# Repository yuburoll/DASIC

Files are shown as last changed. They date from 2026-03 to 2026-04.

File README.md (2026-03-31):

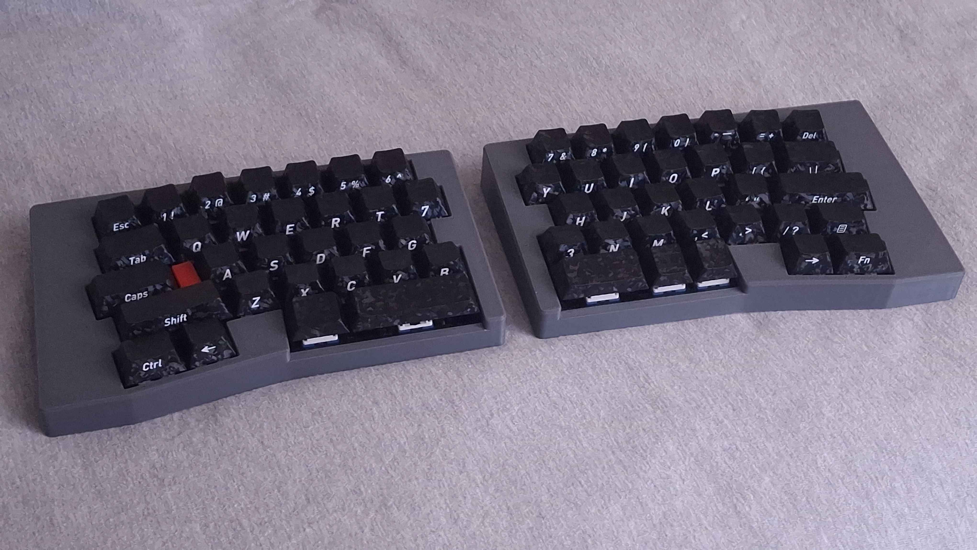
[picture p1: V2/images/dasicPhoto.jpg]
dasicPhoto


# DASIC

(pronounced like DAH-sick)

60-64 key symmetrical row stagger alice style wired split keyboard

The name "dasic"(dasik) is korean traditional dessert, and also is korean pun of [ansic](https://github.com/yuburoll/ANSIC) with many key.

[**V2 README**](V2/README.md)

[**V2 3.75u README**](V2-375u/README.md)

[**V1 README**](V1/README.md) (deprecated since May 22, 2026)

# 다식

60-64 좌우대칭 앨리스 배열 스플릿 키보드

키 수 많은 [안식](https://github.com/yuburoll/ANSIC)이라는 농담을 치고 싶었습니다.

[**V2 설명서**](V2/README_ko.md)

[**V2 3.75u 설명서**](V2-375u/README_ko.md)

[**V1 설명서**](V1/README_ko.md) (2026년 3월 22일부터 지원 종료)

## Licenses

all codes follow MIT license.

all designs and the hardware board follow CC BY-SA 4.0 license.

If you want to make a commercial product, it would be appreciated if you sponsor some bucks for me.

## 라이센스

모든 코드는 MIT license를 따릅니다.

모든 디자인과 하드웨어 보드는 CC BY-SA 4.0 license를 따릅니다.

본 디자인을 가지고 상업활동을 하고 싶으시다면, 몇 푼 정도 후원해주시면 감사하겠습니다...

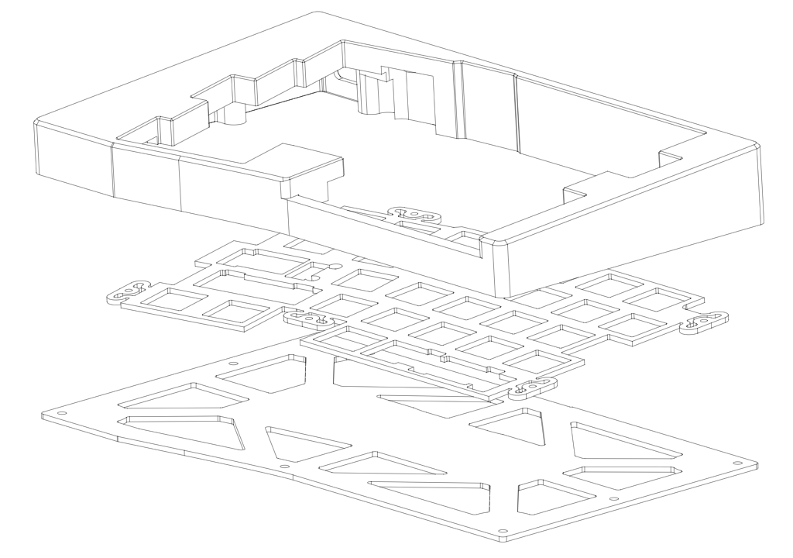
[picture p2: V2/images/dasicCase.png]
dasicCase


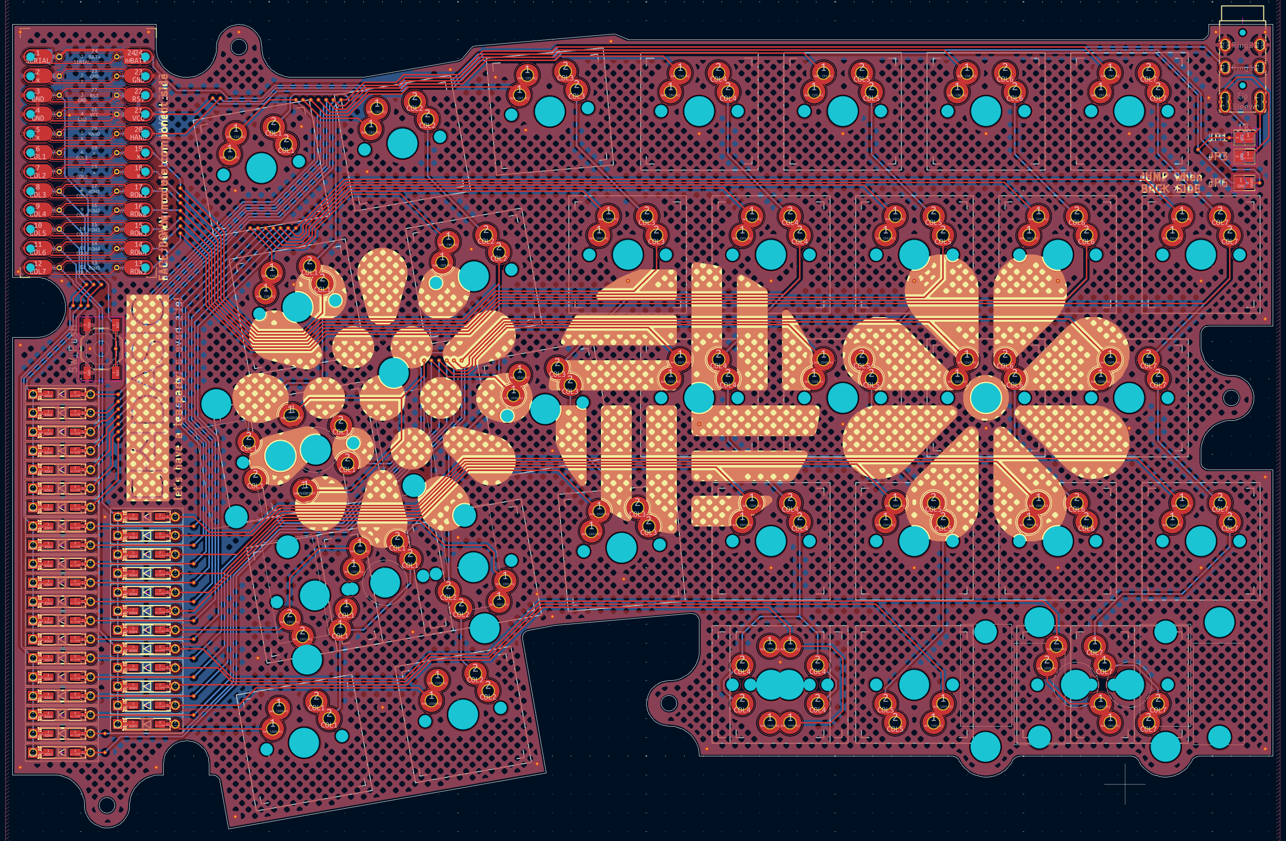
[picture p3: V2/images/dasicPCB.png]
dasicPCB


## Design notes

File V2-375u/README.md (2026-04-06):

# DASIC v2 3.75u

[한국어 설명은 여기에서 보실 수 있습니다](README_ko.md)

(pronounced like DAH-sick)

60-64 key symmetrical row stagger alice style wired split keyboard

The name "dasic"(dasik) is korean traditional dessert, and also is korean pun of [ansic](https://github.com/yuburoll/ANSIC) with many key.

this keyboard have difference on thumb cluster, which have 3.75u length.(the original one have 4u)

you may check the keycap layout under the Default Keymap title.

## Preparation

- 2x pro micro form factor dev board

- 2x dasic PCB Boards, provided from the repo

- 1x printed case sets, 2 parts total, provided from the repo

- 2x 1.5-1.6T keyboard plates, provided from the repo

- 2x 1.5-1.6T back plates, provided from the repo

- 0-2x 0.5u blocker, provided from the repo, normally 1

- 64x diodes

- 24-34x M2x6 screws, flathead

- 2x PJ320A 1/8(3.5mm) TRRS connector

- 2x 4x4x1.5mm surface mount tact switches

- 1x 1/8(3.5mm) TRRS cable

- 2-6x PCB Mounted 2u Keyboard Stabilizers, normally 4 

- 60-64x MX Keyswitches, normally 62

- 8x 10mm bumpon stickers

- A set of Keycaps, Tenkeyless ANSI layout

## Build Guides and Miscellaneous

[**DASIC Build Guide**](documents/buildGuide.md)

there's some notices before the build:

- **You may flash the firmware before soldering the dev board.**

- Assemble dev board with 2.5mm height pin headers on front side, assume that components side are faced down.

- Jump every jumpers on back side.

- You may use mill-max styled socket to make the keyswitches hot-swappable.

- If you soldering mill-max, be aware of Caps&Enter position, align well to center of pad mask.

## Default Keymap

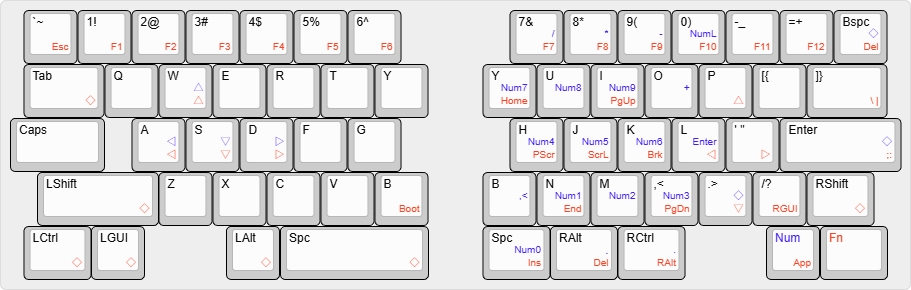
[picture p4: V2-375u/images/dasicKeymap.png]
dasicKeymap


There are two more layers - Num, Fn - which can be noticed by the color legends. ◇ Means Transparent; which uses base keymap.

Holding the color legend key swaps the layer.

You may refer to the picture below for the keycap layout:

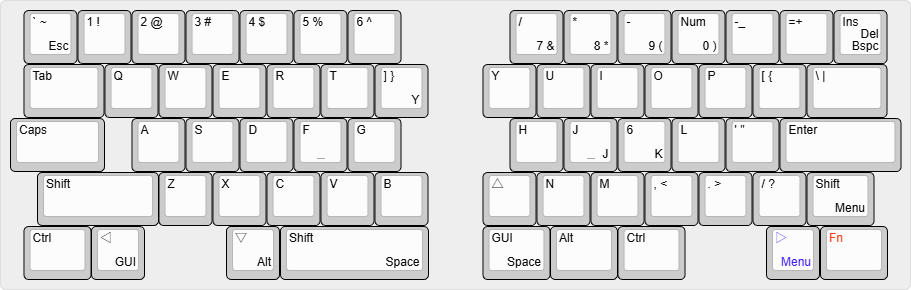
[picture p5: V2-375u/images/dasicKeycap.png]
dasicKeycap


## Licenses

all codes follow MIT license.

all designs and the hardware board follow CC BY-SA 4.0 license.

If you want to make a commercial product, it would be appreciated if you sponsor some bucks for me.

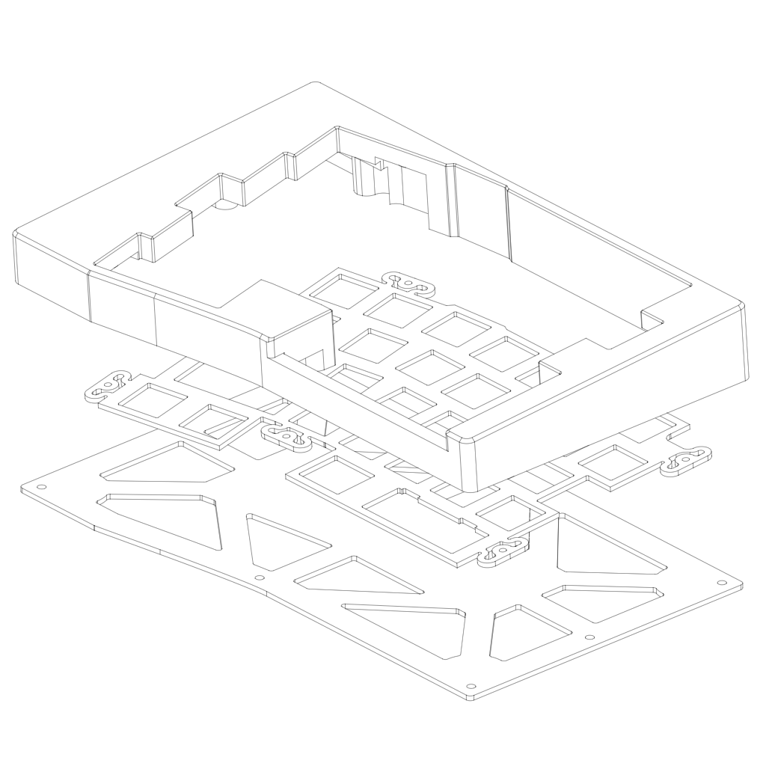
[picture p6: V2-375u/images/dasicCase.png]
dasicCase


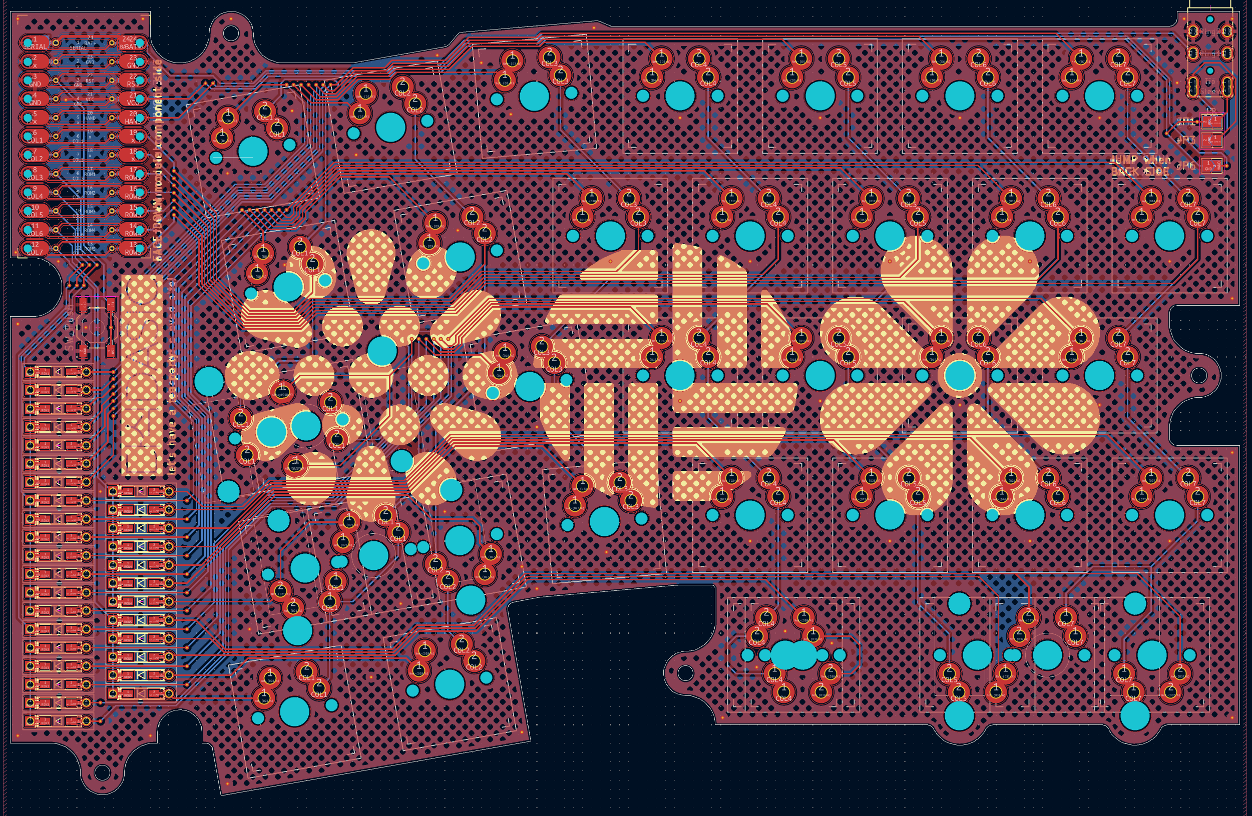
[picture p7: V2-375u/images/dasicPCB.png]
dasicPCB


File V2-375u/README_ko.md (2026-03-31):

# DASIC 다식 v2 3.75u

60-64 좌우대칭 앨리스 배열 스플릿 키보드

키 수 많은 [안식](https://github.com/yuburoll/ANSIC)이라는 농담을 치고 싶었습니다.

기존 버젼은 썸클러스터 부분의 길이가 4u이지만, 이 버젼은 3.75u이며 핫스왑 기판에 제약이 없습니다.

실제 레이아웃이 어떻게 보여지는지는 기본 키맵 항목에 있는 키배치를 참고해주세요.

## 준비물

- 2x 프로마이크로 폼팩터 개발보드

- 2x 다식 PCB 보드, 본 레포지토리에서 제공

- 1x 케이스 출력물 세트, 왼쪽 오른쪽 총 2파츠, 본 레포지토리에서 제공

- 2x 1.5-1.6T 키보드 보강판, 본 레포지토리에서 제공

- 2x 1.5-1.6T 백플레이트, 본 레포지토리에서 제공

- 0-2x 0.5u 블로커, 본 레포지토리에서 제공, 보통 1개

- 64x 다이오드

- 24-34x M2x6 접시머리 나사

- 2x PJ320A 1/8(3.5mm) TRRS 커넥터

- 2x 4x4x1.5mm smd 소형 스위치

- 1x 1/8(3.5mm) TRRS 케이블(TRS도 됩니다)

- 2-6x 무보강용 2u 스태빌라이저, 보통 4개(텐키리스 세트)

- 60-64x MX 키스위치, 보통 62개

- 8x 10mm 범폰 스티커

- 키캡 세트, 텐키리스 ANSI 레이아웃 (일부 커스텀 키보드 배열도 가능)

## 빌드가이드와 추가자료

[**빌드가이드 보러가기**](documents/buildGuide_ko.md)

주의사항 요약은 다음과 같습니다.

- **개발보드를 납땜하기 전에 우선 펌웨어를 개발보드에 올려주세요.**

- 개발보드를 동봉된 2.5mm 높이 핀헤더와 함께 pcb의 앞면에 납땜해주세요. 개발보드 부품이 있는 면이 아래를 향해야 합니다.

- pcb 뒷면의 모든 점퍼를 땜해주세요.

- 납땜 기판을 핫스왑 가능하게 만들고 싶다면 밀맥스 형태의 소켓을 대신 땜해야 합니다.

- 밀맥스를 땜할 땐 캡스락과 엔터 위치에 조심하세요. 뒷면 패드마스크의 중앙에 오도록 해주세요.

## 기본 키맵

dasicKeymap

fn, num 레이어가 추가로 있습니다. 색깔 각인으로 어떻게 작동하는지 확인하실 수 있습니다. ◇는 기본 키맵의 키를 이용한다는 이야기입니다.

우하단의 fn, num키를 길게 누르면 해당 레이어로 바뀝니다.

키캡을 꼽을 땐 다음 이미지를 참고해주세요.

dasicKeycap

## 라이센스

모든 코드는 MIT license를 따릅니다.

모든 디자인과 하드웨어 보드는 CC BY-SA 4.0 license를 따릅니다.

본 디자인을 가지고 상업활동을 하고 싶으시다면, 몇 푼 정도 후원해주시면 감사하겠습니다...

dasicCase

dasicPCB

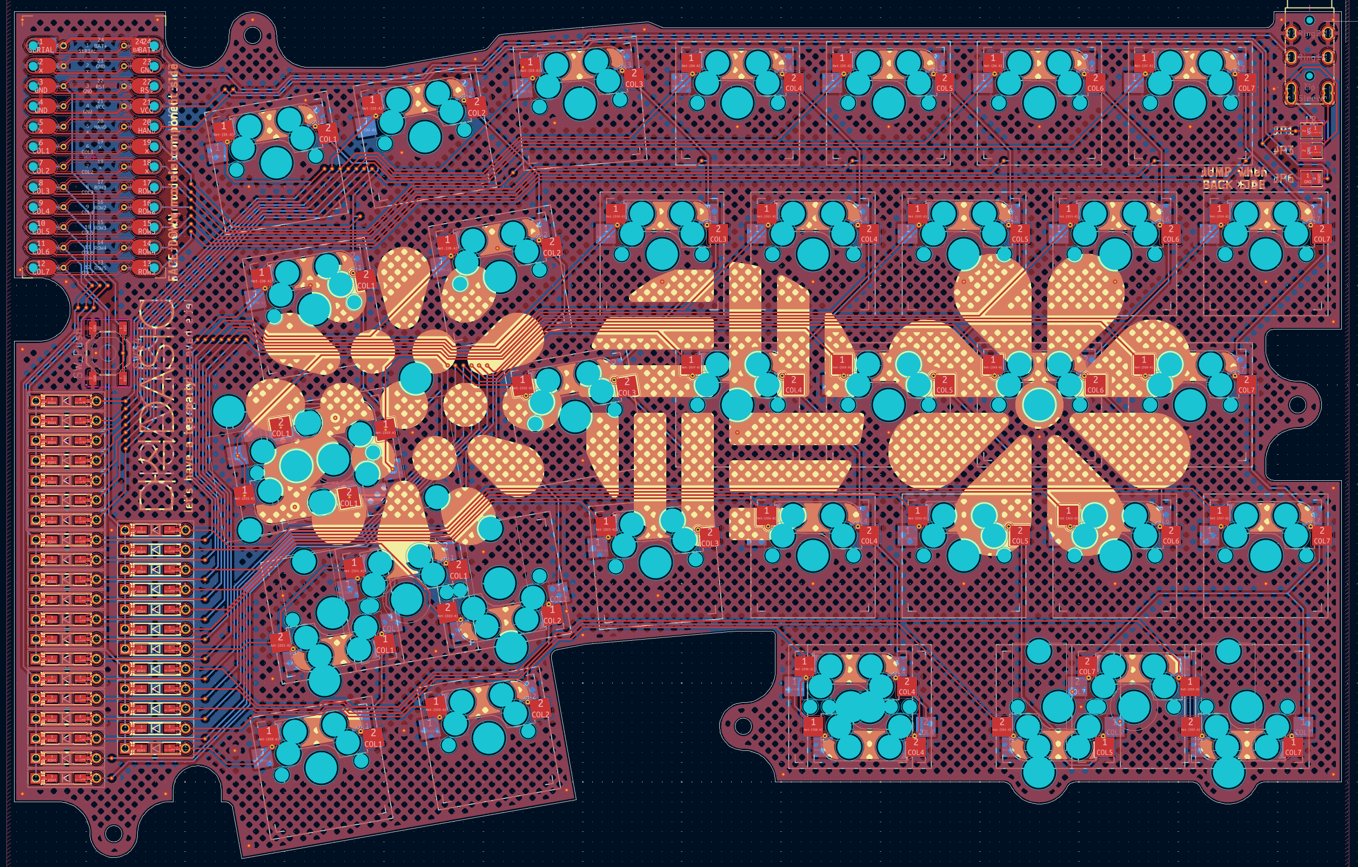
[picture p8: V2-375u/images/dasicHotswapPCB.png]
dasicHotswapPCB


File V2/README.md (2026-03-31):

dasicPhoto

# DASIC v2

[한국어 설명은 여기에서 보실 수 있습니다](README_ko.md)

(pronounced like DAH-sick)

60-64 key symmetrical row stagger alice style wired split keyboard

The name "dasic"(dasik) is korean traditional dessert, and also is korean pun of [ansic](https://github.com/yuburoll/ANSIC) with many key.

this keyboard have solder-only PCB, but you can also choose [hotswappable PCB](hotswapVersion) with some major difference.

## Preparation

- 2x pro micro form factor dev board

- 2x dasic PCB Boards, provided from the repo

- 1x printed case sets, 2 parts total, provided from the repo

- 2x 1.5-1.6T keyboard plates, provided from the repo

- 2x 1.5-1.6T back plates, provided from the repo

- 0-2x 0.5u blocker, provided from the repo, normally 1

- 64x diodes

- 24-34x M2x6 screws, flathead

- 2x PJ320A 1/8(3.5mm) TRRS connector

- 2x 4x4x1.5mm surface mount tact switches

- 1x 1/8(3.5mm) TRRS cable

- 2-6x PCB Mounted 2u Keyboard Stabilizers, normally 4 

- 60-64x MX Keyswitches, normally 62

- 8x 10mm bumpon stickers

- A set of Keycaps, Full-size ANSI layout

## Build Guides and Miscellaneous

[**DASIC Build Guide**](documents/buildGuide.md)

[**Misc 1: Hotswappable PCB**](hotswapVersion)

[**Misc 2: Legacy versions**](../V1)

there's some notices before the build:

- **You may flash the firmware before soldering the dev board.**

- Assemble dev board with 2.5mm height pin headers on front side, assume that components side are faced down.

- Jump every jumpers on back side.

- You may use mill-max styled socket to make the keyswitches hot-swappable.

- If you soldering mill-max, be aware of Caps&Enter position, align well to center of pad mask.

## Default Keymap

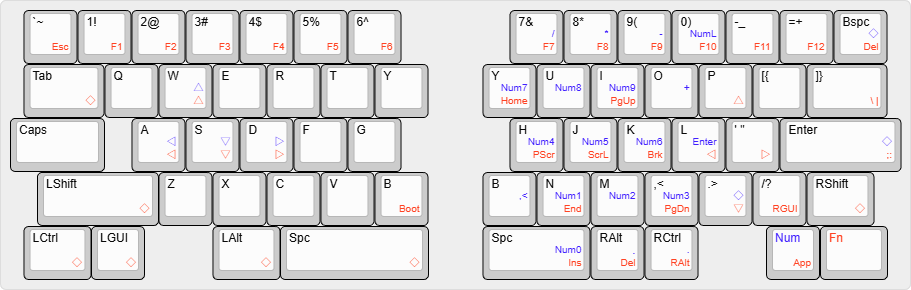
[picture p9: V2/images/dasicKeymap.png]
dasicKeymap


There are two more layers - Num, Fn - which can be noticed by the color legends. ◇ Means Transparent; which uses base keymap.

Holding the color legend key swaps the layer.

You may refer to the picture below for the keycap layout:

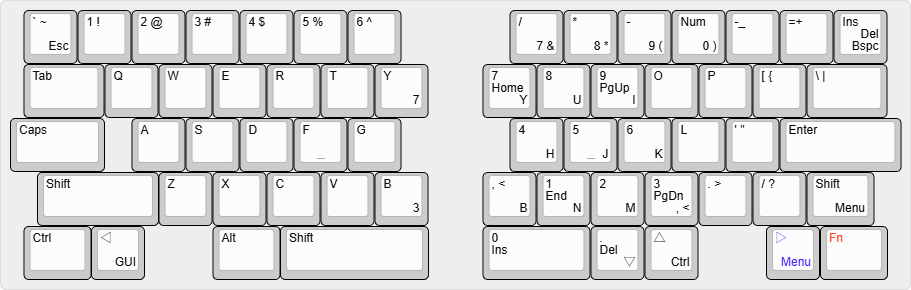
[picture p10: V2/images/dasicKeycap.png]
dasicKeycap


## Licenses

all codes follow MIT license.

all designs and the hardware board follow CC BY-SA 4.0 license.

If you want to make a commercial product, it would be appreciated if you sponsor some bucks for me.

dasicCase

dasicPCB

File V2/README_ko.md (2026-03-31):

dasicPhoto

# DASIC 다식 v2

60-64 좌우대칭 앨리스 배열 스플릿 키보드

키 수 많은 [안식](https://github.com/yuburoll/ANSIC)이라는 농담을 치고 싶었습니다.

솔더링만 지원하는 기판이지만, 조금 제한이 있는 [핫스왑 버젼](hotswapVersion)을 만들어두었습니다.

## 준비물

- 2x 프로마이크로 폼팩터 개발보드

- 2x 다식 PCB 보드, 본 레포지토리에서 제공

- 1x 케이스 출력물 세트, 왼쪽 오른쪽 총 2파츠, 본 레포지토리에서 제공

- 2x 1.5-1.6T 키보드 보강판, 본 레포지토리에서 제공

- 2x 1.5-1.6T 백플레이트, 본 레포지토리에서 제공

- 0-2x 0.5u 블로커, 본 레포지토리에서 제공, 보통 1개

- 64x 다이오드

- 24-34x M2x6 접시머리 나사

- 2x PJ320A 1/8(3.5mm) TRRS 커넥터

- 2x 4x4x1.5mm smd 소형 스위치

- 1x 1/8(3.5mm) TRRS 케이블(TRS도 됩니다)

- 2-6x 무보강용 2u 스태빌라이저, 보통 4개(텐키리스 세트)

- 60-64x MX 키스위치, 보통 62개

- 8x 10mm 범폰 스티커

- 키캡 세트, 풀배열 ANSI 레이아웃

## 빌드가이드와 추가자료

[**빌드가이드 보러가기**](documents/buildGuide_ko.md)

[**추가자료 1: 핫스왑 PCB**](hotswapVersion)

[**추가자료 2: 이전 버젼**](../V1)

주의사항 요약은 다음과 같습니다.

- **개발보드를 납땜하기 전에 우선 펌웨어를 개발보드에 올려주세요.**

- 개발보드를 동봉된 2.5mm 높이 핀헤더와 함께 pcb의 앞면에 납땜해주세요. 개발보드 부품이 있는 면이 아래를 향해야 합니다.

- pcb 뒷면의 모든 점퍼를 땜해주세요.

- 납땜 기판을 핫스왑 가능하게 만들고 싶다면 밀맥스 형태의 소켓을 대신 땜해야 합니다.

- 밀맥스를 땜할 땐 캡스락과 엔터 위치에 조심하세요. 뒷면 패드마스크의 중앙에 오도록 해주세요.

## 기본 키맵

dasicKeymap

fn, num 레이어가 추가로 있습니다. 색깔 각인으로 어떻게 작동하는지 확인하실 수 있습니다. ◇는 기본 키맵의 키를 이용한다는 이야기입니다.

우하단의 fn, num키를 길게 누르면 해당 레이어로 바뀝니다.

키캡을 꼽을 땐 다음 이미지를 참고해주세요.

dasicKeycap

## 라이센스

모든 코드는 MIT license를 따릅니다.

모든 디자인과 하드웨어 보드는 CC BY-SA 4.0 license를 따릅니다.

본 디자인을 가지고 상업활동을 하고 싶으시다면, 몇 푼 정도 후원해주시면 감사하겠습니다...

dasicCase

dasicPCB

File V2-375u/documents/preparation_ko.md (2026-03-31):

# 준비물과 구매처

알리익스프레스 링크와 한국에서 구할 수 있는 곳의 링크를 올립니다. 국내에서 구하는 게 더 나은 경우 알리 링크를 굳이 올리진 않습니다.

(2026년 2월 21일 기준입니다. 작동하지 않는 링크가 있을 수도 있습니다.)

다른 좋은 스토어나 다른 좋은 구매처가 있다면 그 쪽을 이용해주세요. 구매 링크는 예시일 뿐이며, 일절 저에게 수익이 들어오지 않습니다...

## 다식 pcb 보드 2장

- JLCPCB에서 맡기면 배송비 포함 25달러 가량에 제조할 수 있습니다. https://jlcpcb.com/

- [거버 폴더](../gerber) 안의 [dasic375-gerber.zip(솔더링판)](../gerber/solder/dasic375-gerber.zip)이나  [dasic375Hotswap-gerber.zip(핫스왑판)](../gerber/hotswap/dasic375Hotswap-gerber.zip)을 다운로드 받아 사이트에 올려주시면 됩니다.

## 보강판과 백플레이트

- JLCPCB에서 FR4 1.6mm HASL(no lead)(중요)를 맡기거나, 3d 프린팅을 직접 하거나(이 두께는 보통 안 해줍니다), 임의의 판재 레이저/cnc커팅점에서 백플레이트와 보강판을 맡깁니다. 각각 원하는 도면으로 구매합니다. 백플레이트와 보강판을 각각 한 쌍씩 준비해주세요.

- JLCPCB에 맡길 땐 거버 폴더[(솔더링판 및 백플레이트)](../case/platesGerber)안의 하위 폴더들에서 원하는 도면의 거버 압축 파일을 다운로드 받아 사이트에 업로드하면 됩니다. https://jlcpcb.com/

- fdm이나 sls 출력을 할 땐 [stl 폴더](../case/stl) 안의 내용물들 중 원하는 사양을 다운로드 받아 출력해주시면 됩니다.

- 레이저/cnc커팅을 맡길 땐 [platesVector 폴더](../case/platesVector) 내에 있는 dxf 파일이나 svg 파일 도면을 전달드리면 됩니다. 원본 사이즈대로 인쇄해달라면 해주실 겁니다.

## 3d 프린팅된 케이스 한 쌍과 0.5u 블로커

- JLC3dp에서 맡기면 약 8~15달러에 한 쪽씩 sls 레진으로 제조해 줍니다. 위의 pcb 보드와 같이 구매해주세요. https://jlc3dp.com/

- 아니면, 직접 fdm 3d 프린팅해서 만들거나 출력대행을 찾아서 프린팅해 저렴하게 구성해도 좋습니다.

- fdm이나 sls 출력을 할 땐 [케이스 폴더](../case/stl) 안의 내용물들 중 원하는 사양을 다운로드 받아 출력소에 전달해주시면 됩니다.

- fdm 출력에는 bridged라고 표기되어있는 쪽이 좋습니다. 출력물의 뜨는 부분을 고정해주는 브릿지가 있어, 출력물을 견고하게 만들 수 있습니다.

- Tilt4deg라고 적혀져 있는 것은 4도 틸트가 추가로 되어있는 버젼이며, 기존 버젼과 같은 백플레이트를 사용합니다.

- 블로커를 프린팅할 땐 fdm 출력의 경우 BlockerScrew 버젼을 추천합니다. sls의 경우 BlockerHalfScrew를 사용할 수는 있겠으나, 유연성이 없는 재질이라면 BlockerScrew버젼을 사용해 주시기 바랍니다.

## rp2040 pro micro 보드 2개

- 알리: https://ko.aliexpress.com/item/1005009890367599.html
 
- 국내: https://smartstore.naver.com/plumkit/products/12026654291

https://www.nologo.tech/ 이 회사의 rp2040 ProMicro 제품을 상정하고 있습니다. sparkfun의 rp2040 보드도 잘 작동하리라고 생각합니다.

## PJ320A 3.5mm TRRS 커넥터 2개

- 알리: https://ko.aliexpress.com/item/32951864590.html
 
- 국내: https://m.smartstore.naver.com/costec/products/12661336420  5.6mm로 구매해주세요.
  
## (선택) 4x4x1.5mm smd 스위치 2개

- 국내: https://smartstore.naver.com/domekit/products/4315666002

## (핫스왑) MX 핫스왑 소켓 70개

- 알리: https://ko.aliexpress.com/item/1005007232040760.html
 
- 국내1: https://smartstore.naver.com/sagaklabs/products/9090497445

- 국내2: https://smartstore.naver.com/nana-inc/products/8240806382

- 국내3: https://smartstore.naver.com/around_life/products/10187682355

## 다이오드 64개

납땜이 익숙하지 않다면 THT 다이오드를 쓰시는 걸 추천합니다. 니퍼도 준비해 주세요.

- 국내(THT): https://smartstore.naver.com/ic11401/products/618129765
 
- 국내(SMD): https://smartstore.naver.com/parts_world/products/8350720438

## M2x6 접시머리 스크류 나사 40개
 
- 국내: https://smartstore.naver.com/riwootool/products/5561795590 옵션 선택에 주의해주세요

## 2u 무보강 스태빌라이저

- 사막 스테빌: https://smartstore.naver.com/morningcraft/products/13072728359

- 체리 스테빌(스냅인): https://smartstore.naver.com/swagkey/products/5700949313

- 체리 스테빌(스크류인): https://smartstore.naver.com/swagkey/products/5134034319

## MX용 키스위치 64개와 키캡 세트

- 평소에 좋아하시는 거 구하시면 됩니다. 왼손의 2u 엄지 키의 존재 때문에, 될 수 있으면 키패드가 포함된 풀배열 키캡을 추천드립니다.

## 눈물 범폰 8~10mm 4개

- 다이소에서 8~10mm짜리 유리 미끄럼 방지 패드나 충격 방지를 찾으면 저렴하게 쓸만한 물건을 구할 수 있습니다.

## 3.5mm TRRS 케이블 1개 (TRS도 됩니다)

- 아무 케이블이든 좋고, 국내에서 쉽게 구하실 수 있을 겁니다.

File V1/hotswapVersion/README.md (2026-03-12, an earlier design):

# DASIC hotswap version

this folder is for hotswap version of dasic.

### Notice

- This version uses different PCB and keyboard plate layout. you may fabricate these from this folder.

- This version uses same case, same backplate, same blocker, same firmware. you may fabricate these from the master folder.

- This version can use kailh hot swap socket or such.

- This version can split/merge 2.25u shift position.

- This version cannot change thumb layout to other one. this forces left hand to 1.25u/2.75u layout and right hand to 2u/1u/1u layout.

- This version cannot change Caps/Enter keycap to another sized one.

- Be careful when soldering hot swap socket for space bar positions - they will be soldered by small pad pieces, so you may solder these more tightly.

# 다식 핫스왑 버젼

이 폴더는 다식의 핫스왑 버젼의 정보를 담고 있습니다.

### 주의사항

- 이 버젼은 PCB와 보강판의 배열이 살짝 다릅니다. 이 폴더 안에 있는 내용물을 사용해주세요.

- 케이스와 백플레이트, 블로커, 펌웨어는 동일한 걸 사용합니다. 상위 폴더의 내용물을 사용해주세요.

- 카일 핫스왑 소켓, 혹은 이와 호환되는 핫스왑 소켓이 필요합니다.

- 여전히 2.25u 쉬프트 포지션의 키는 스플릿하거나 합칠 수 있습니다.

- 엄지 4u 키 레이아웃은 납땜판과는 달리 바꿀 수 없습니다. 왼손은 1.25u/2.75u로 고정되고, 오른손은 2u/1u/1u로 고정됩니다.

- Caps/Enter도 서로 다른 키캡으로 바꿀 수 없습니다.

- 스페이스 바 포지션의 핫스왑 소켓을 납땜할 땐 주의해주세요. 패드 조각이 조금밖에 남지 않아서, 좀 더 단단하게 땜하셔야 합니다.

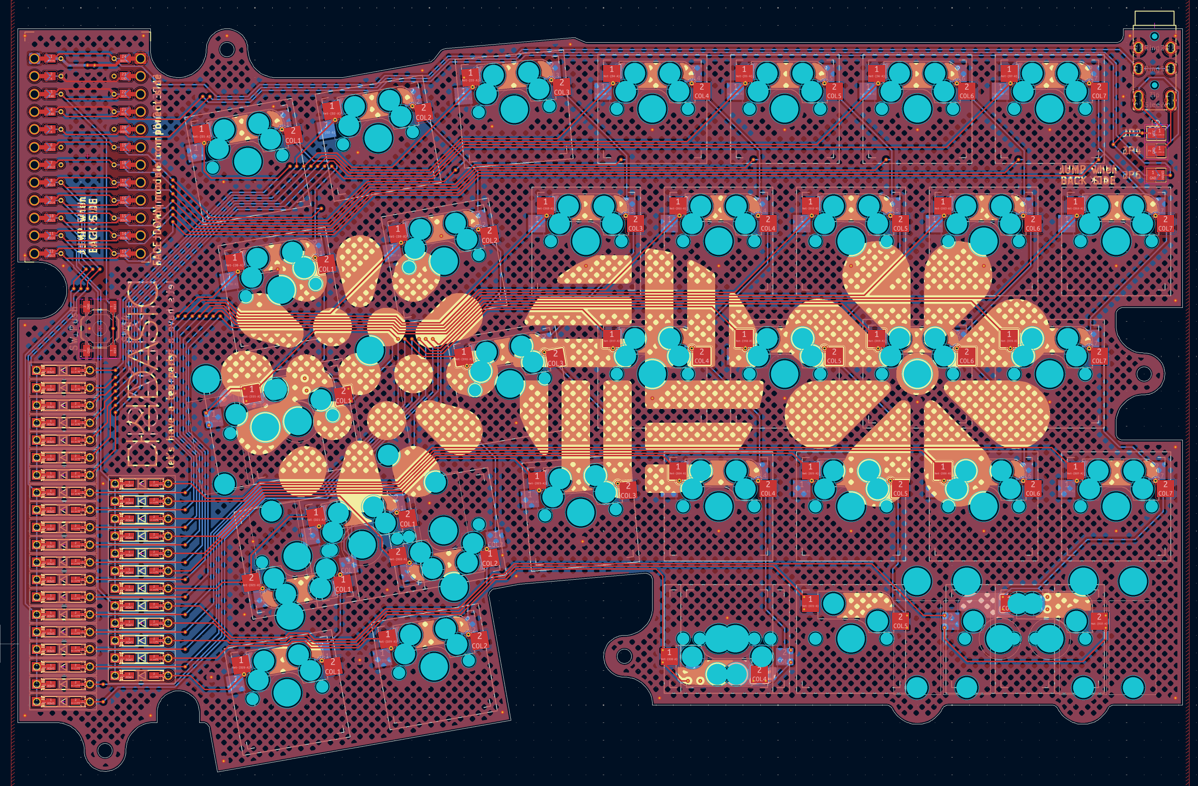
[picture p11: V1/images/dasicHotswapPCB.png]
dasicHotswap


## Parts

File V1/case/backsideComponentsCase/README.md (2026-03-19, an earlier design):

# DASIC backside component case

this is folder for DASIC's Backside Component Case.

this have big differences compared to the basic build so I didn't put this on the reference case, but this have more stronger structure.

I recommend this case if you want to get tilted case.

Major differences at build:

- You may put Dev board modules and TRRS jacks on BACK SIDE.

- Dev boards' components must face PCB side, shown like build guide.

- Jump every jumpers of dev board at FRONT SIDE.

- for TRRS jack and handness, Jump JP2, JP4, JP5 for LEFT SIDE, Jump JP1, JP3, JP6 for RIGHT SIDE.

- plates and backplates use default ones.

# 다식 뒷면 부품용 케이스

이 폴더는 다식의 뒷면 부품용 케이스를 위한 폴더입니다.

기본 빌드랑 차이가 있기 때문에 메인 폴더에 집어넣지 않고 따로 구분해두었지만, 좀 더 단단한 구조를 가지고 있습니다. (알루미늄 cnc도 맡길 수 있지 않을까 생각합니다. 도면에서 나사구멍을 전부 M2로 지정해야 하겠지만요.)

틸팅된 케이스를 만드신다면 이 쪽을 추천합니다.

빌드의 주요 차이점은 다음과 같습니다.

- 뒷면에 개발보드 모듈과 trrs 잭을 배치합니다.

- 빌드가이드에서처럼, 개발보드의 부품들은 pcb 면을 바라보도록 해야 합니다.

- 개발보드의 점퍼는 앞면에서 땜합니다.

- 왼손은 JP2, JP4, JP5를 점프해야 하고 오른손은 JP1, JP3, JP6을 점프해야 합니다. 왼손 오른손 결정과 TRRS 잭을 위한 점퍼들입니다. 

- 보강판과 백플레이트는 기본 제공되는 사양을 쓰면 됩니다.

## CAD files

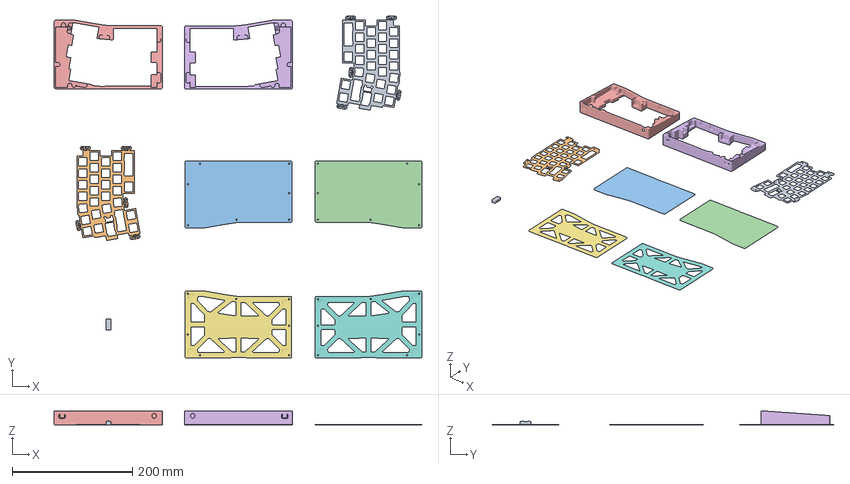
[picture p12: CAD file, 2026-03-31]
V2-375u/case/3mf/dasic375.3mf
610.5 x 567.9 x 24.0 mm
dasic375PlateL.stl x 2
dasicBackPlateL.stl x 2
dasic375CaseFDMbridgeL.stl x 2
dasicBackplateLightL.stl x 2
dasicBlockerScrew.stl

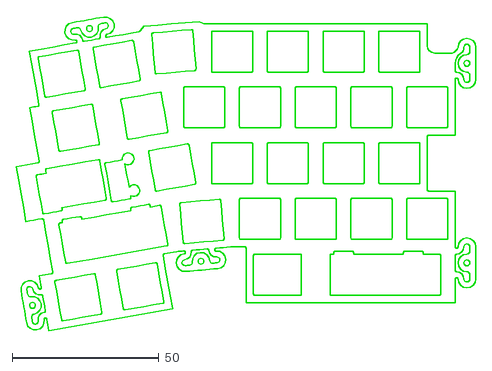
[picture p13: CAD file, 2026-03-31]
V2-375u/case/platesVector/dasic375Plate.dxf
156.5 x 107.2

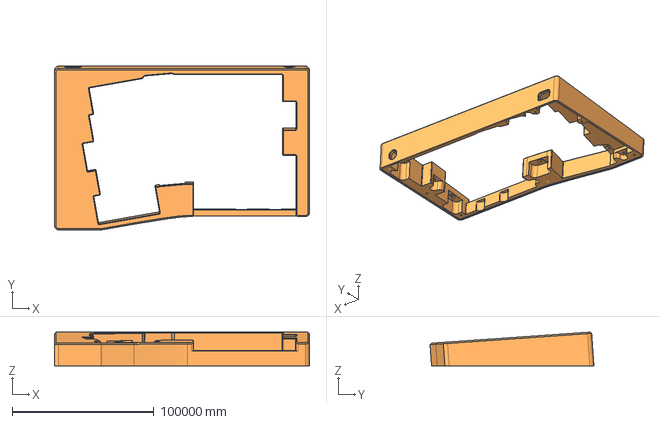
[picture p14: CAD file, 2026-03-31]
V2-375u/case/step/dasic375CaseL.stp
180000.0 x 115730.7 x 23878.4 mm

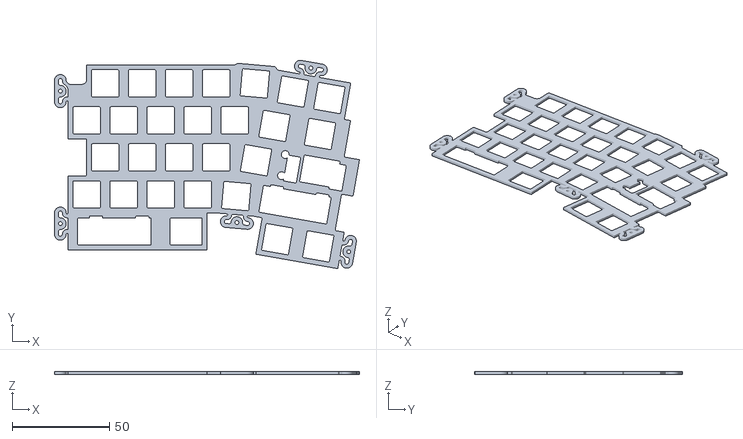
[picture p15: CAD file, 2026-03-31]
V2-375u/case/stl/dasic375PlateR.stl
156.5 x 106.9 x 1.50

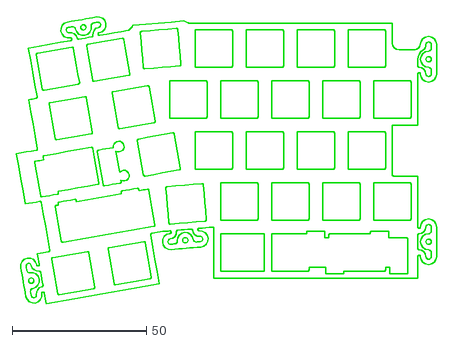
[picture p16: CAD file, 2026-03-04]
V2/case/platesVector/dasicPlate.dxf
156.5 x 107.2

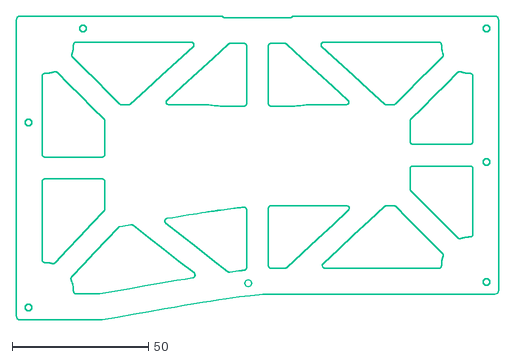
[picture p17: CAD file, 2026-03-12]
V2-375u/case/platesVector/dasicBackplateLight.dxf
177.0 x 111.4

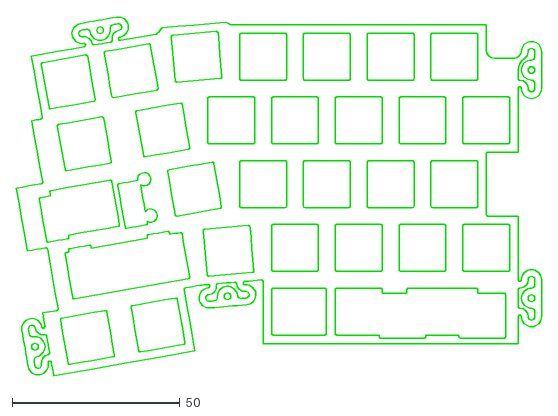
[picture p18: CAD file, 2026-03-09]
V2/hotswapVersion/HotswapPlate/dasicHotswapPlate.dxf
156.5 x 107.2

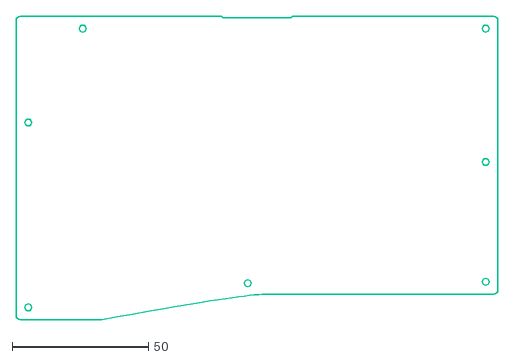
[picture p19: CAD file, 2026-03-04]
V2-375u/case/platesVector/dasicBackplate.dxf
177.0 x 111.4

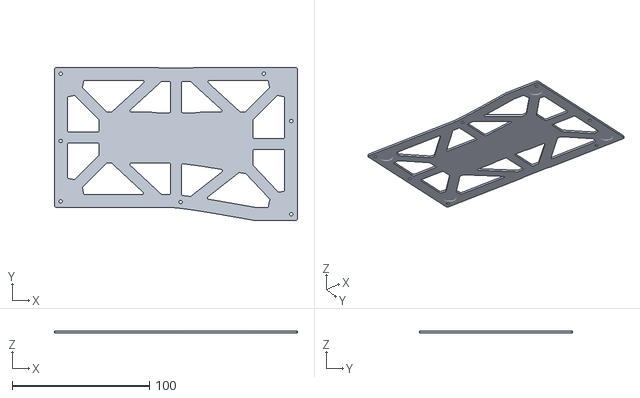
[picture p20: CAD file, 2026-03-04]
V2-375u/case/stl/dasicBackplateLightR.stl
177.0 x 111.4 x 1.50

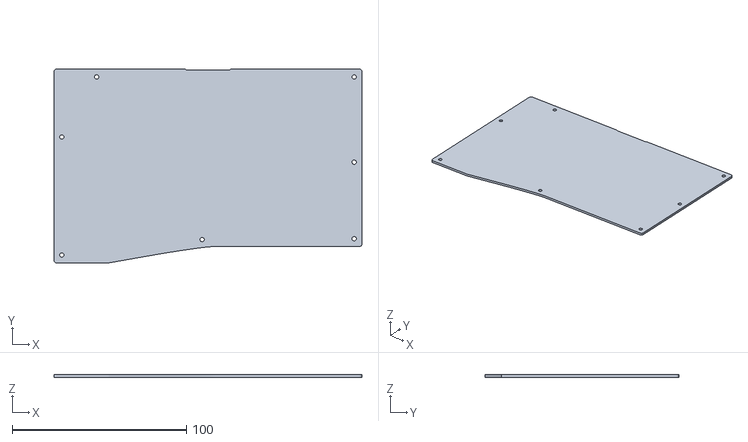
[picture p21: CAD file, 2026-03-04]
V2-375u/case/stl/dasicBackplateL.stl
177.0 x 111.4 x 1.50

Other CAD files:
V2/case/3mf/dasic.3mf
V2/case/step/dasicCaseV2R.stp
V2/case/stl/dasicPlateR.stl
V2/hotswapVersion/HotswapPlate/dasicHotswapPlateL.stl
V2-375u/case/step/dasic375CaseR.stp
V2-375u/case/stl/dasic375PlateL.stl
V2/case/step/dasicCaseV2L.stp
V2/case/stl/dasicPlateL.stl
V1/case/3mf/dasic.3mf
V1/case/backsideComponentsCase/dasicCaseBacksideComponentL.stp
V1/case/backsideComponentsCase/dasicCaseBacksideComponentR.stp
V1/case/step/dasicCaseL.stp
V1/case/step/dasicCaseR.stp
V1/case/step/dasicCaseTilt4degL.stp
V1/case/step/dasicCaseTilt4degR.stp
V1/case/stl/dasicPlateL.stl
V1/case/stl/dasicPlateR.stl
V1/hotswapVersion/HotswapPlate/dasicHotswapPlateL.stl
V2-375u/case/step/dasicBlockerHalfScrew.stp
V2-375u/case/step/dasicBlockerScrew.stp
V2-375u/case/stl/dasicBackplateLightL.stl
V2-375u/case/stl/dasicBlockerHalfScrew.stl
V2-375u/case/stl/dasicBlockerScrew.stl

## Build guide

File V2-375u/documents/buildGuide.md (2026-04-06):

# Build Guide

This is the build guide for DASIC.

This documents is translated by generative AI, so there can be some misleading texts.

**Images of the build guide are based on V1. I'm currently working on V2. read direction first, carefully.**

### Additional Resources

[**Soldering Tips**](solderingTip.md)

### Estimated Fabrication BOM

for only one set of DASIC:

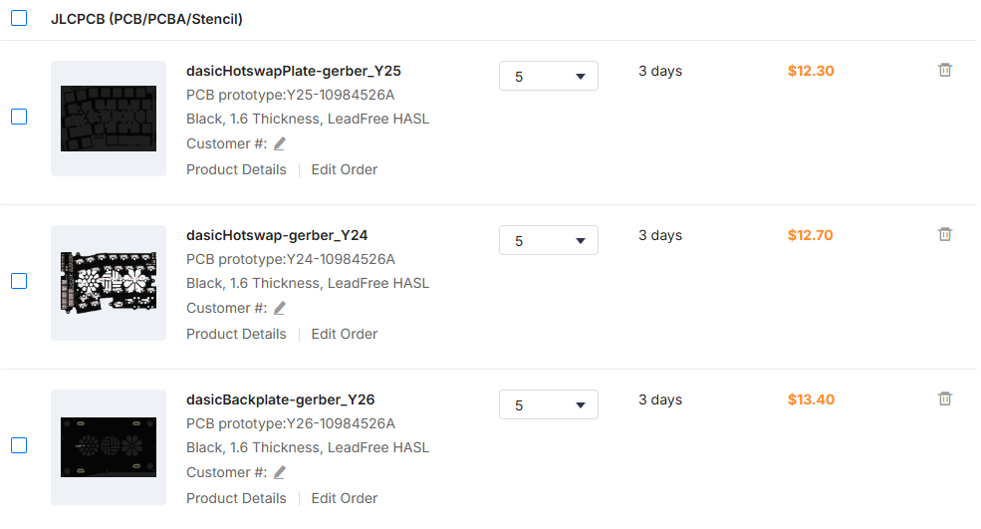
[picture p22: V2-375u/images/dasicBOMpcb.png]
fabPCB


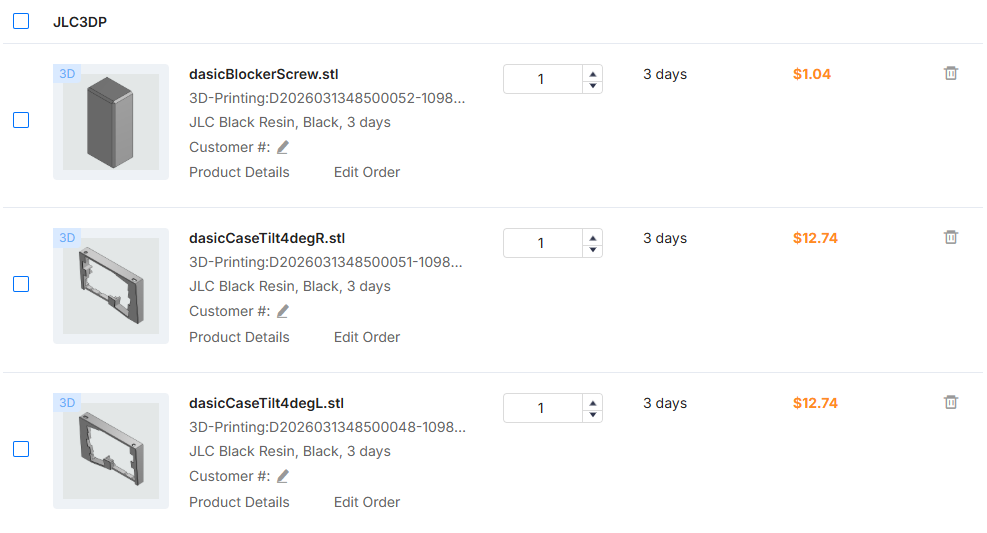
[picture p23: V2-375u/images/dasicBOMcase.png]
fabCase


for five set of DASIC:

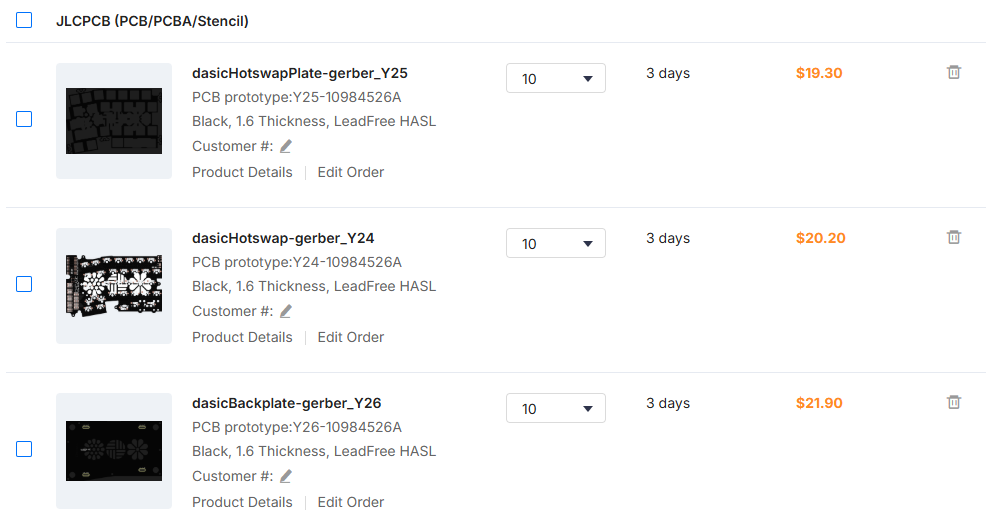
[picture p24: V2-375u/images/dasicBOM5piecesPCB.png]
fab10PCB


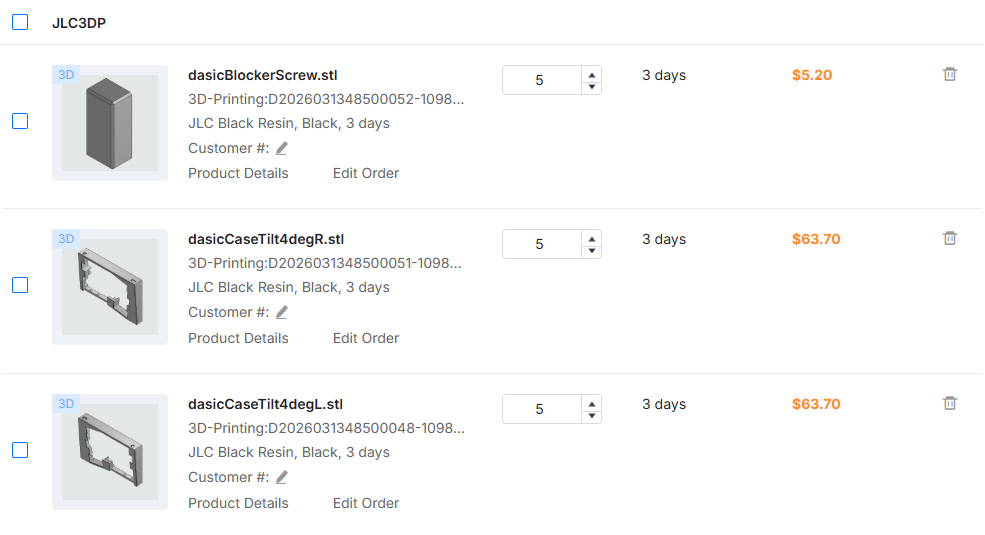
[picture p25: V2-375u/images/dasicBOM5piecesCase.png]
fab5Case


The lowest per-unit cost comes from building five sets (approximately $45 each), but even building just two sets can bring the per-unit manufacturing cost down to around $55.

## Flashing Firmware onto the Controller Board

This guide assumes the use of an rp2040 board.

Hold the Boot button on the controller board while connecting the USB cable, and a removable drive will appear. (This is called DFU mode.)

Drag and drop the .uf2 file from the [uf2examples folder](../firmware/nologoRP2040qmk/examples) into the removable drive to flash the firmware. I recommend flashing the Vial firmware.

The firmware uses [QMK](https://qmk.fm/). If you want to build your own firmware, copy the "modubu" folder from the "firmware/qmk" directory into the "qmk_firmware\keyboards" directory and build it using QMK MSYS.

Once fully assembled, the Boot button becomes inaccessible, which causes issues. Therefore, **I recommend flashing the firmware before soldering the controller board**.

To enter DFU mode after flashing the firmware, hold the bottommost outermost switch (Left Ctrl or Fn position) while connecting the keyboard.

## Soldering the Controller Board

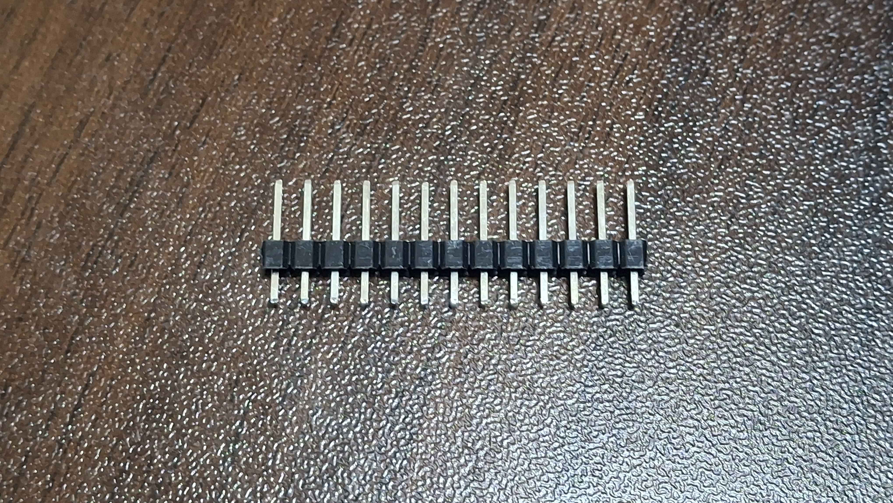
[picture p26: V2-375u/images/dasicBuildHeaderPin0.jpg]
headerPin0


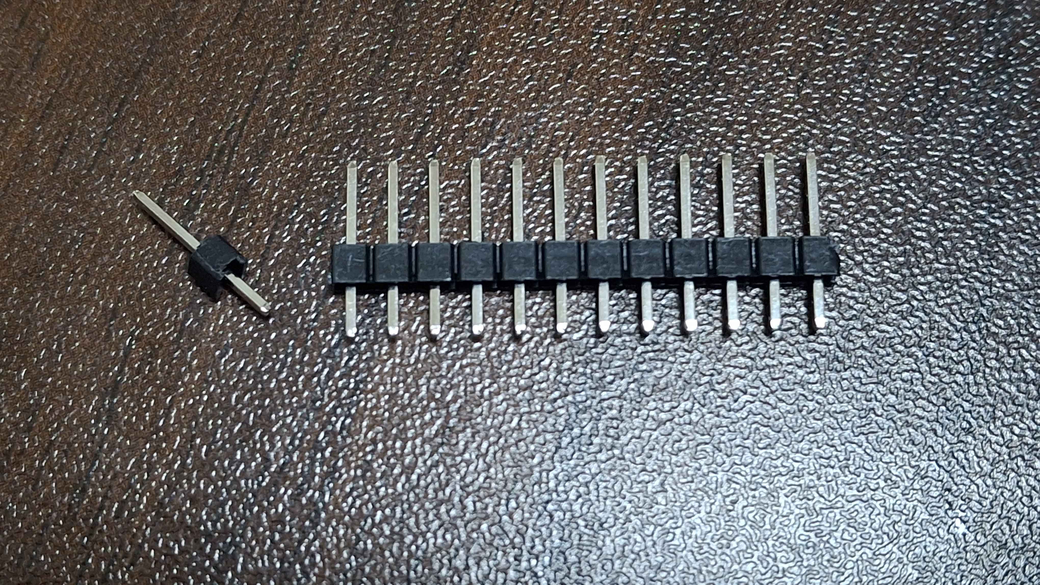
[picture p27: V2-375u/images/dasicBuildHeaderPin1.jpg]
headerPin1


First, detach one row from the header pins included with the controller board. This is because the header pin closest to the USB port will not be soldered.

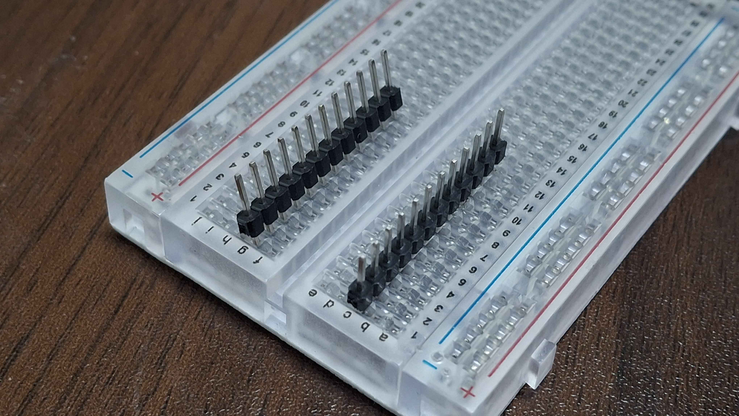
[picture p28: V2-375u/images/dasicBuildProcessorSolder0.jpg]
processorSolder0


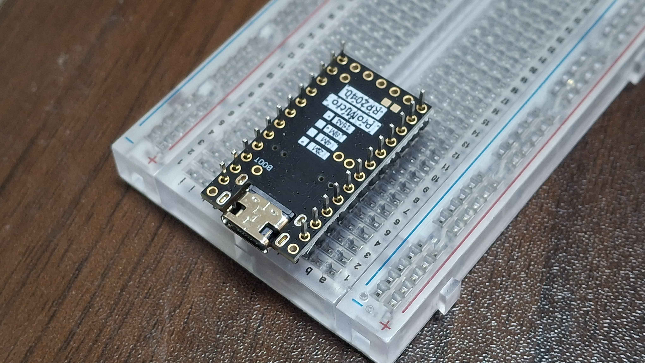
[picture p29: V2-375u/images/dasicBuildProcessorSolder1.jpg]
processorSolder1


Insert and solder the header pins **with the processor components facing downward, and with the pin closest to the USB port left empty**.

If you have a breadboard, seating the header pins on it as shown above makes soldering easier.

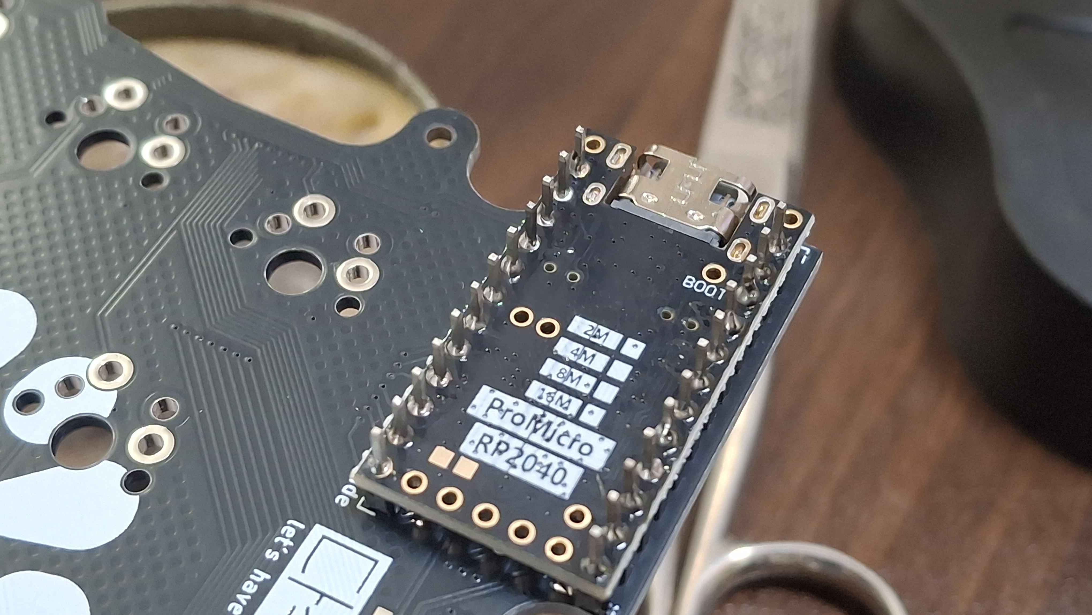
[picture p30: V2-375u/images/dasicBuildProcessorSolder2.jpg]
processorSolder2


Solder the processor board you just prepared onto the PCB.

**The side where the processor board is mounted becomes the BACK of the PCB, and the opposite side becomes the FRONT. Flip the PCB according to whether it is for the left or right hand, then mount the processor board.**

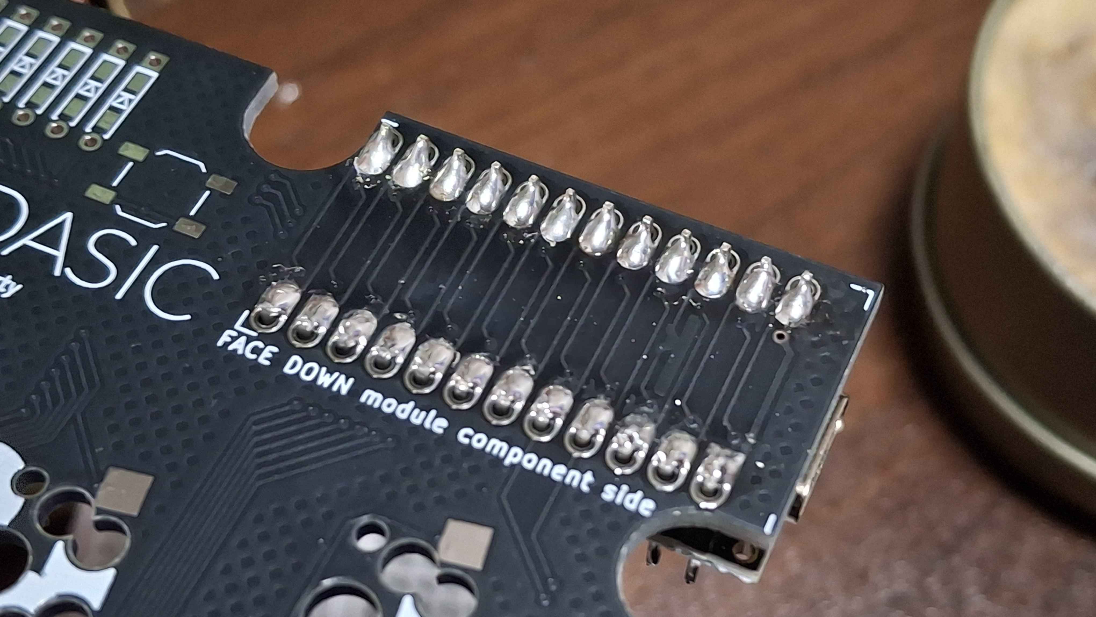
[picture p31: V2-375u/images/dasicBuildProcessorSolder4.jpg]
processorSolder4


Looking at the front of the PCB, solder all the header pins to pads.

There is no THT hole in the center, and pads are positioned above and below. Please apply a generous amount of solder to connect the pads and pins.

## Soldering the Connector & Jumping

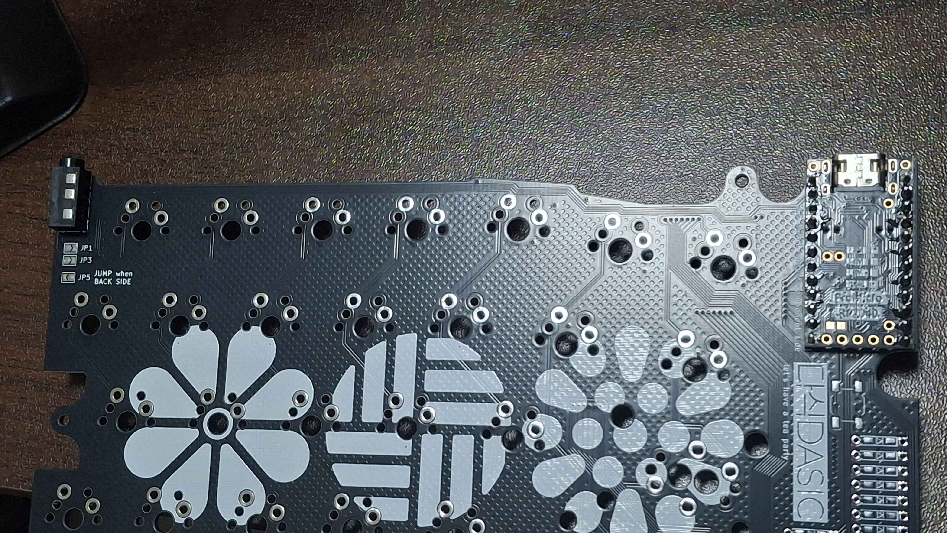
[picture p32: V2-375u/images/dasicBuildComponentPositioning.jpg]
componentPositioning


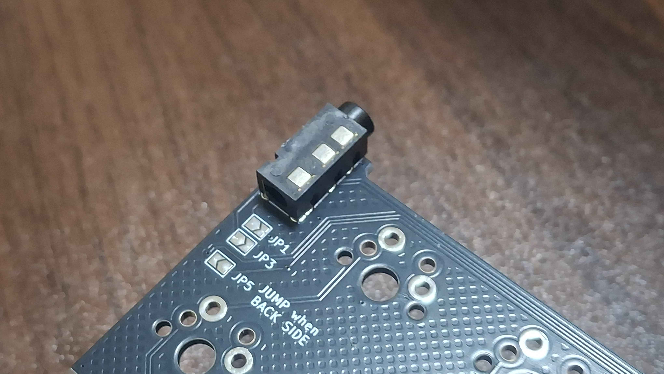
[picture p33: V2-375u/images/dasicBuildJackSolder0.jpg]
jackSolder0


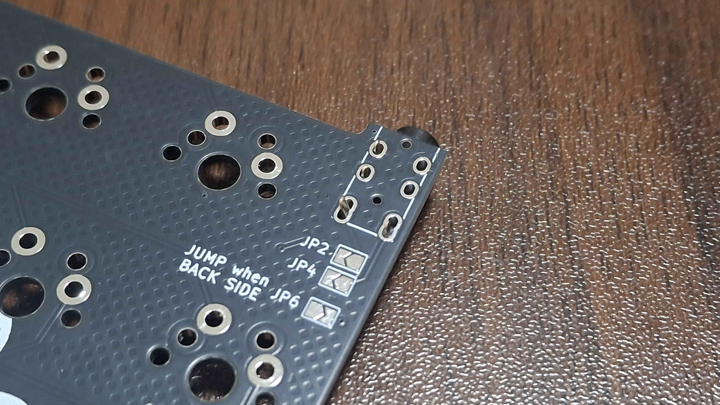
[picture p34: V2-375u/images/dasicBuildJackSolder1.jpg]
jackSolder1


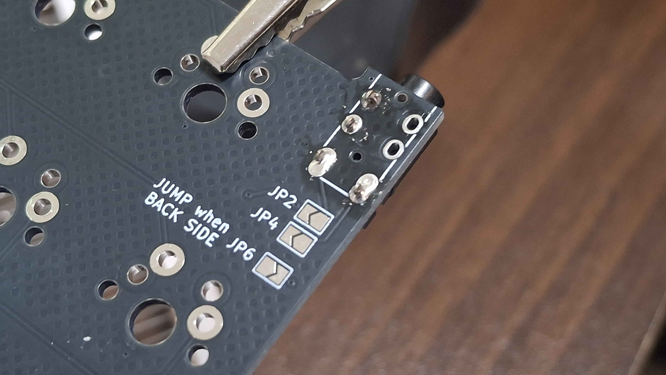
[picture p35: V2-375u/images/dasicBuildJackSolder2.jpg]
jackSolder2


Position the TRRS connector so that it sits on the back side of each hand, and solder from the front side. Using masking tape or similar to hold it in place while soldering is recommended.

While looking at back side, bridge the three jumper pads near the text "JUMP when BACK SIDE" with solder. Do not do this on the opposite side (= the front side where the connector isn't mounted).

When soldering jumpers, first coat the soldering iron tip generously with solder paste, then melt a bead of solder onto it. In this state, bring the bead to the jumper pads and pull away once the two pads are bridged.

- If the pads are bridged but the solder forms a sharp, pointy peak, apply more solder paste to the tip.

- If the pads are not bridging and the solder just beads up on one pad, add more solder to the tip.

- Success is when the pads are bridged with a smooth, dome-shaped bead. Move on to the next jumper.

If it is not working, let the jumper area cool for a moment, apply a generous amount of flux to both the tip and the jumper, and try again.

Do not hesitate; wait patiently and check lead shape.

## Soldering the Diodes

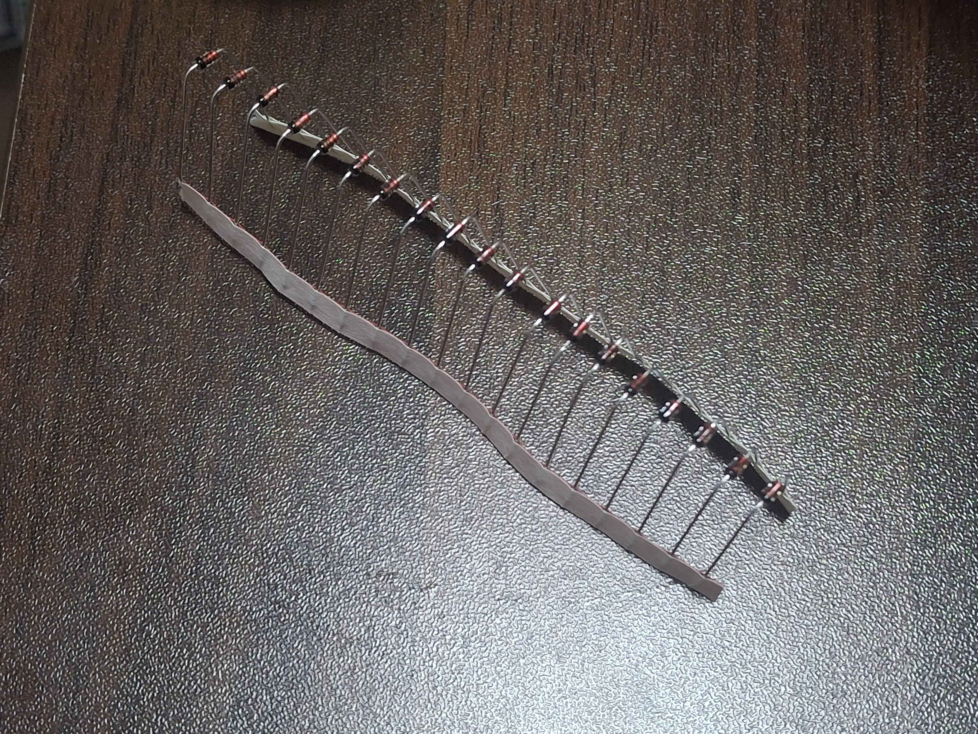
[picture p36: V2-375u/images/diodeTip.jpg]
diodeTip


If using THT diodes, pre-bend the diode legs into a U-shape as shown in the photo above.

Start by soldering the diodes on the column with the greater number first. It does not matter whether you solder from the front or the back, but **all diodes must face outward.**

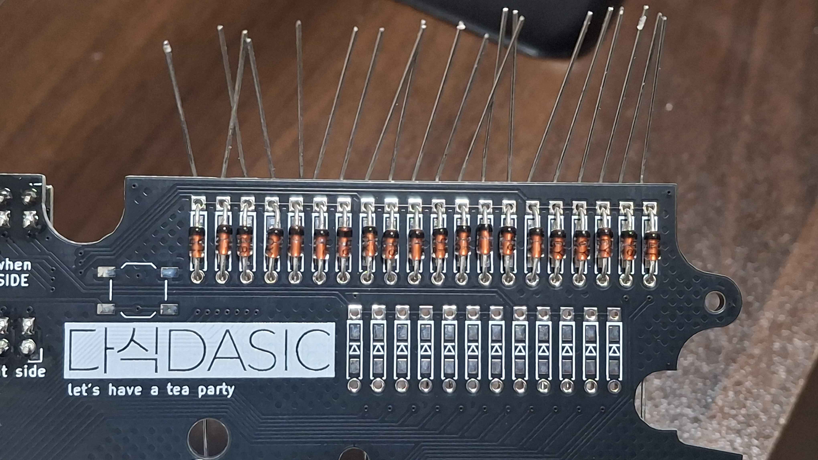
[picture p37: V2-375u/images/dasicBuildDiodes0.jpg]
DiodeSolder0


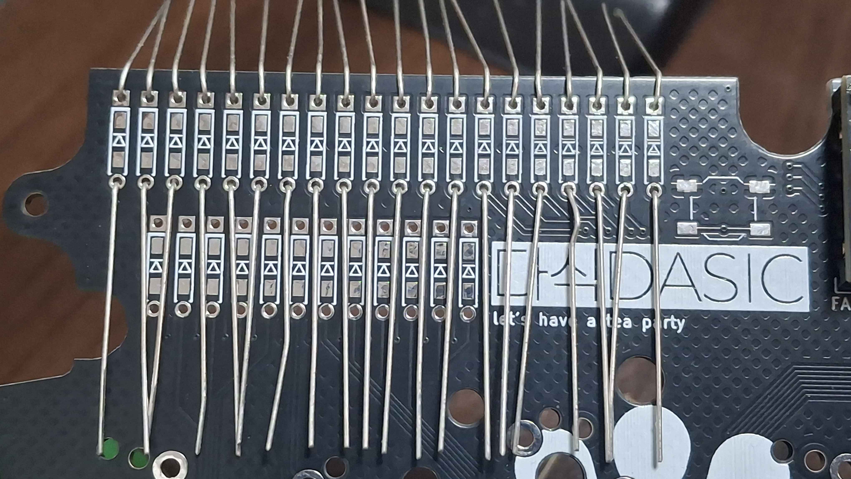
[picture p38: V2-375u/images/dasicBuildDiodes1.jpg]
DiodeSolder1


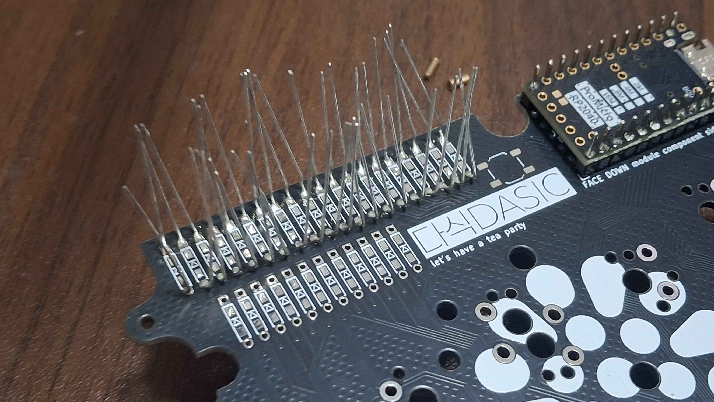
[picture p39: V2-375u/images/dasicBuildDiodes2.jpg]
DiodeSolder2


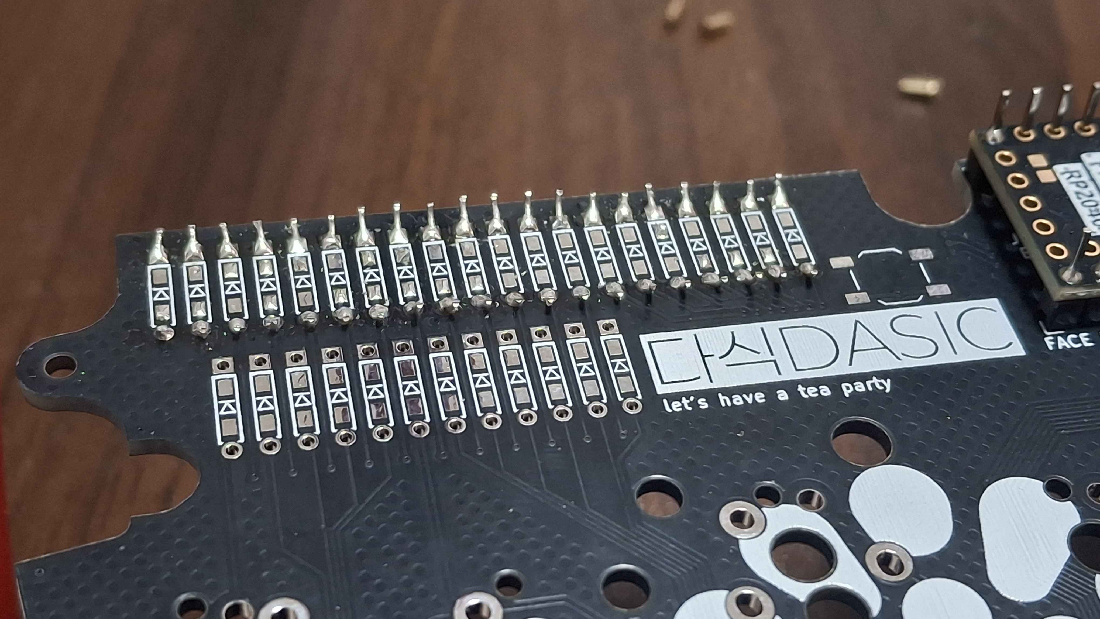
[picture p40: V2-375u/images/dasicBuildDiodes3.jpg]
DiodeSolder3


After soldering, clip all the protruding diode legs with flush cutters. Cut them as close as possible so they do not touch neighboring pads. Always hold the leg with your fingers while cutting to prevent it from flying away.

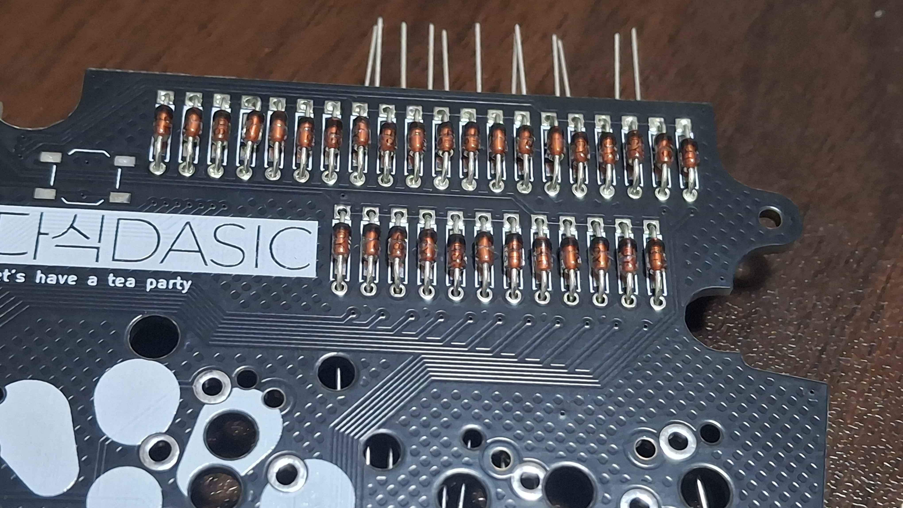
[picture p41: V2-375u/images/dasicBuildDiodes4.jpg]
DiodeSolder4


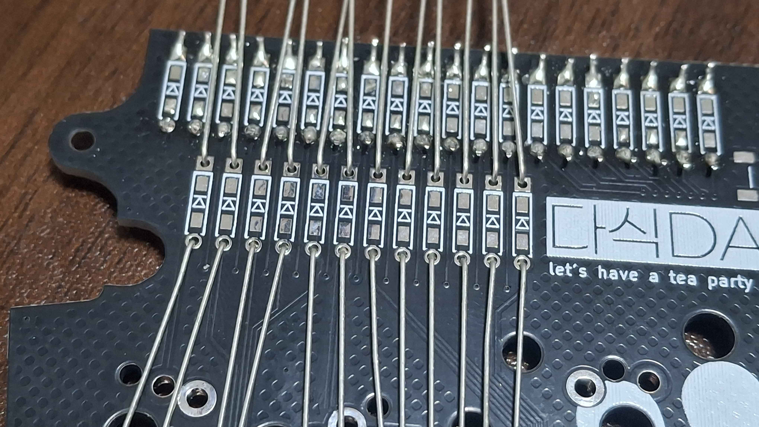
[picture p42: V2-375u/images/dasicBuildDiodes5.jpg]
DiodeSolder5


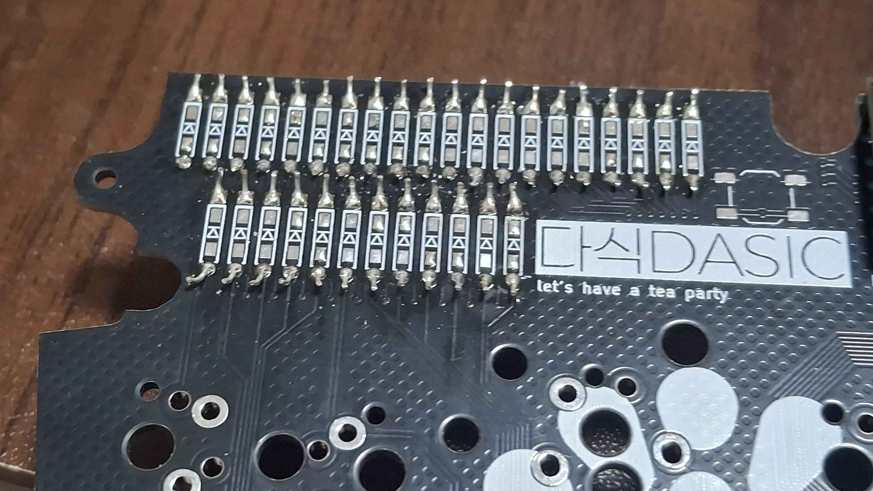
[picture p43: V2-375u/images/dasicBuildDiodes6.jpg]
DiodeSolder6


After finishing the first column, solder the next column in the same order. **Be careful not to let the diode legs touch each other.**

When using SMD diodes, pre-tin one pad at the diode position, then reheat that pad.

When the solder on the pad melts, place one leg of the SMD diode to align it, then solder the other leg.

## (Optional) Soldering the SMD Switch

The SMD switch is connected to the reset pin. For processor boards other than the rp2040, this switch is used to enter DFU mode. solder this switch on the back side.

The method is the same as for SMD diodes. Pre-tin one pad at the switch position, then reheat that pad.

When the solder on the pad melts, place one leg of the switch to align it, then solder the remaining legs.

## (Optional) Soldering Mill-Max Sockets

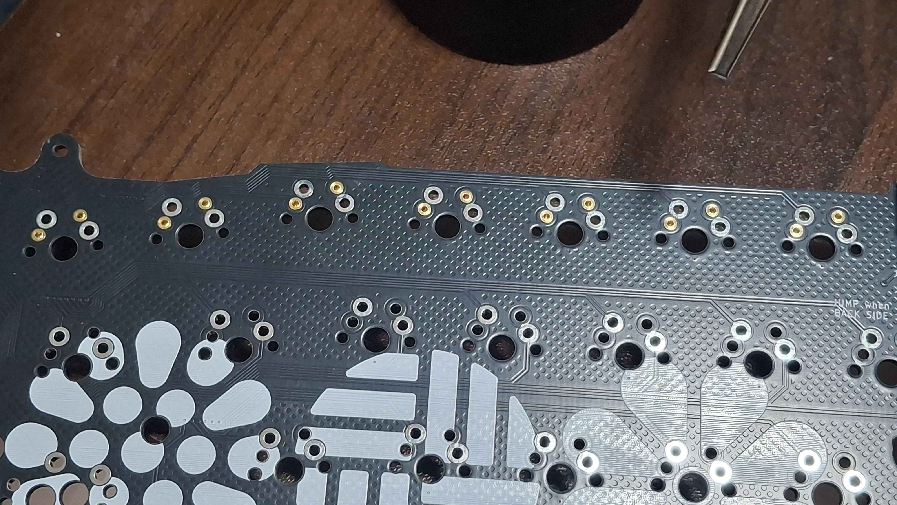
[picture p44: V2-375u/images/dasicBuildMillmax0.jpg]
millmax0


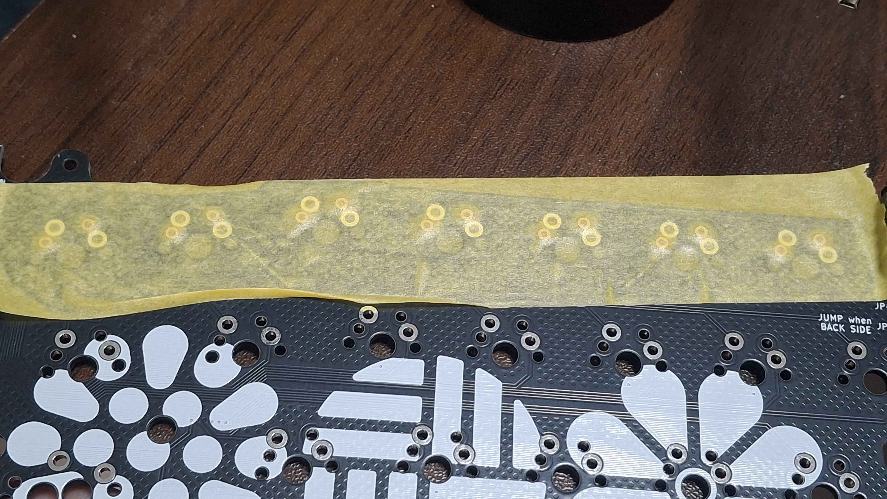
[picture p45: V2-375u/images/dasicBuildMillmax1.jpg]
millmax1


As shown in the photos above, insert the Mill-Max sockets from the front side, secure them with masking tape or similar, and then solder.

The correct position for inserting the Mill-Max sockets is the hole where no pad is visible from the front, and is centered on the pad visible from the back.

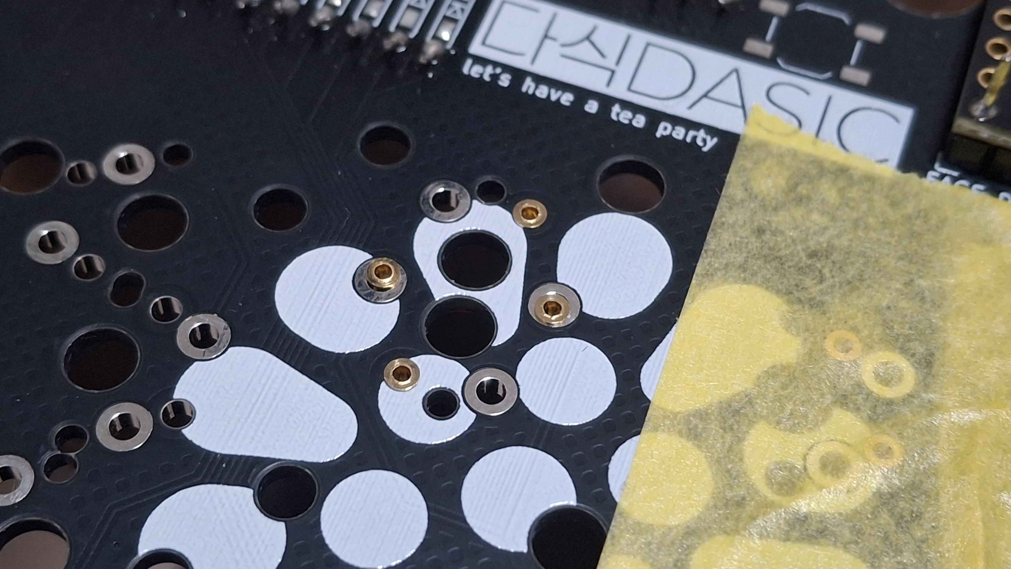
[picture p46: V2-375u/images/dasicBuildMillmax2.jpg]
millmax2


Pay special attention when securing the Mill-Max sockets for the Caps & Enter keys, referring to the photo.

When viewed from the front, they should be aligned to the off-center position; when viewed from the back, they should be centered on the pad shape.

## Assembling the Stabilizers

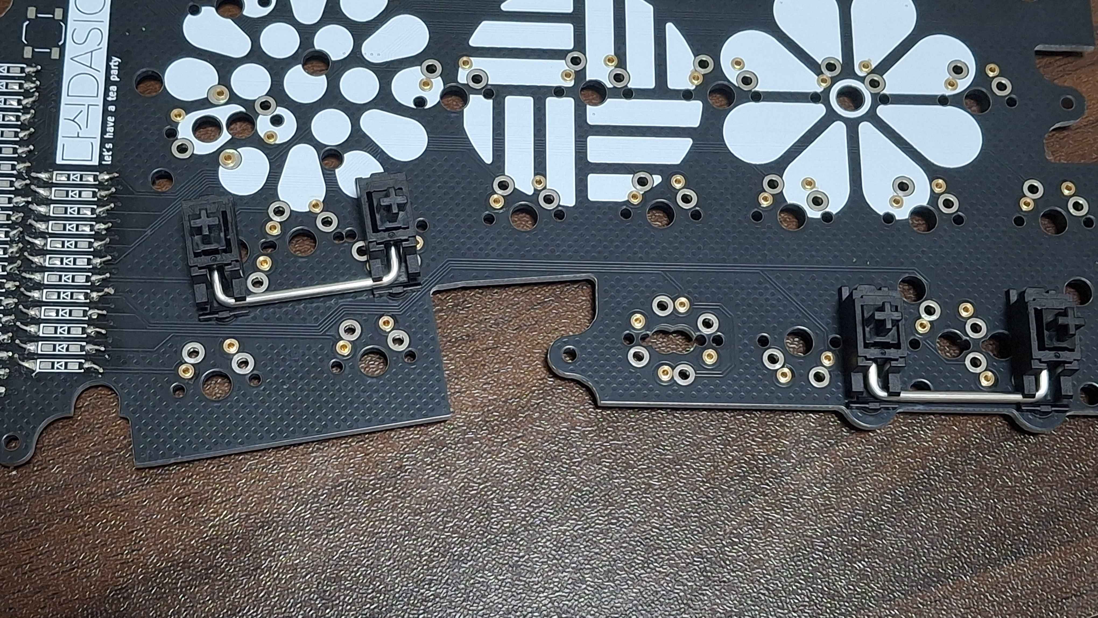
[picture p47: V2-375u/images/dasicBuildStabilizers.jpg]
stabilizers


Install stabilizers on all positions where keycaps of 2u or larger will be placed.

By default, stabilizers are installed in four locations: left Shift, two Spacebar positions, and Enter.

## Checking the Assembly

Inspect the solder joints and their positions to verify that the assembly is correct. The side where the diodes are mounted does not matter as long as the orientation is correct.

## Assembling Switches and the Plate

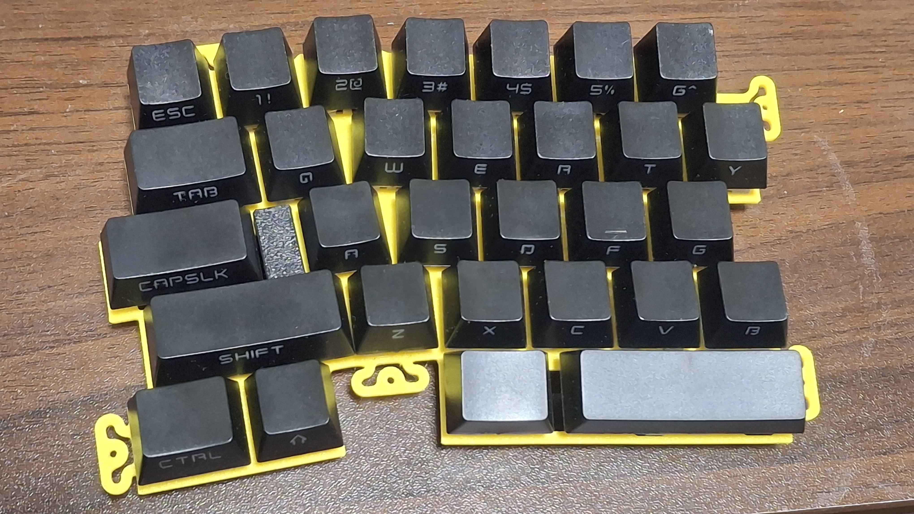
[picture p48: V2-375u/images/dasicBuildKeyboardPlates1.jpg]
plates1


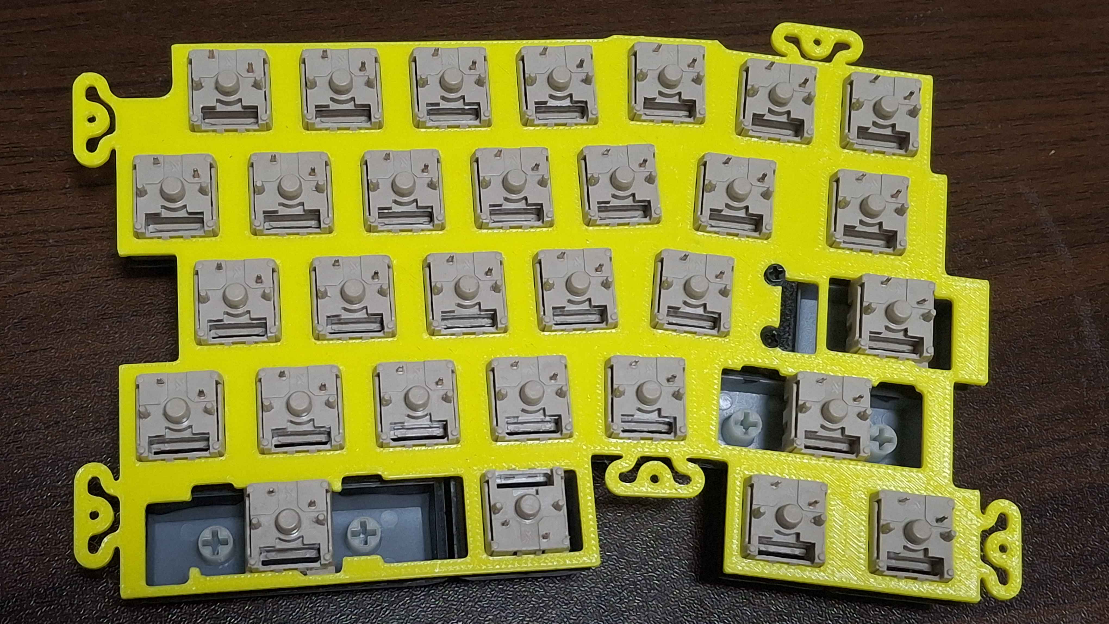
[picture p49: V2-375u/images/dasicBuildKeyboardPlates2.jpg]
plates2


Pre-install the switches and blockers onto the keyboard plate. The photo also shows keycaps installed, but you do not need to install keycaps at this stage.

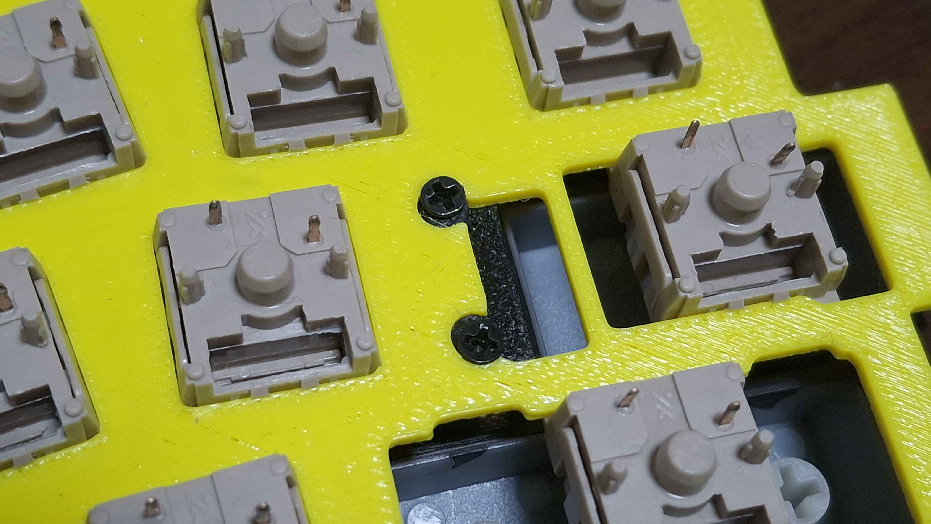
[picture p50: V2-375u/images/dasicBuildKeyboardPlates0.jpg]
plates0


To install the blockers, tighten the screws as shown in the photo above. If using the halfScrew version, hook one protruding end over the plate, then secure the other end with a screw.

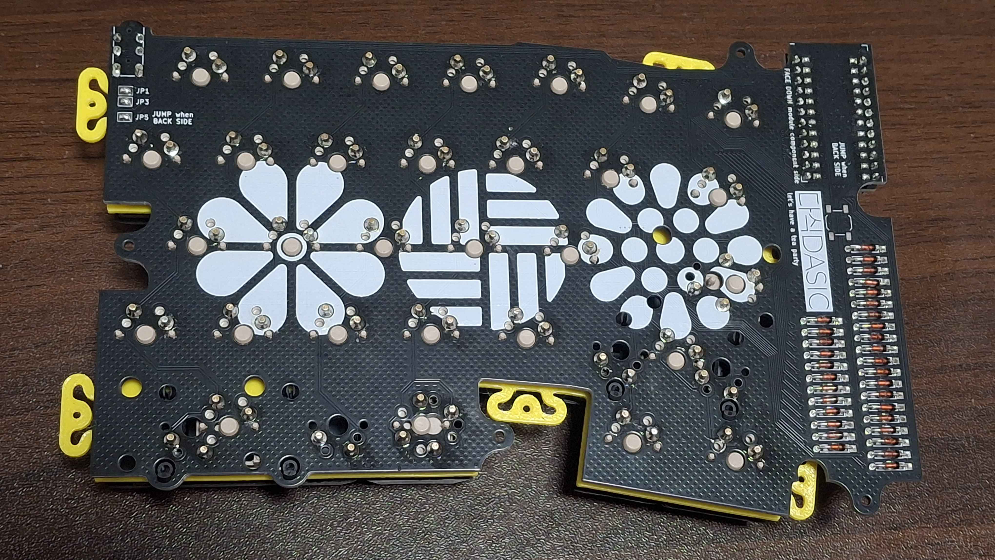
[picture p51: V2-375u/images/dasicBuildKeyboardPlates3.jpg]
plates3


**NOTICE: The photo avove is for V1, you must position dev board and jack on back side (opposite side).**

Place the assembled board on top as shown in the photo, and solder the switches.

## Assembling the Case

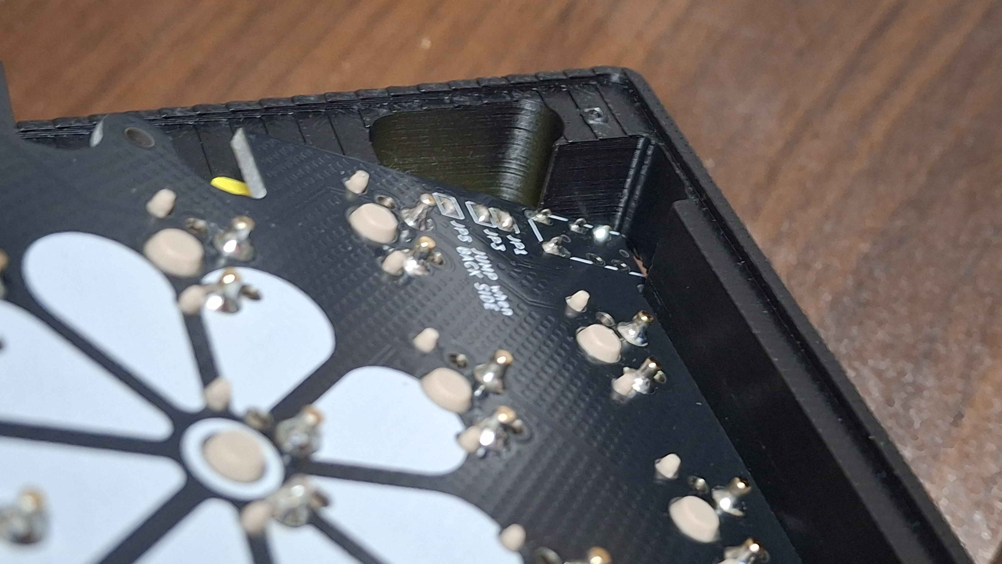
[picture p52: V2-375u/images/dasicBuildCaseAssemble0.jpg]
case0


**NOTICE: The photo avove is for V1, you must position dev board and jack on back side (opposite side).**

Insert the plate and PCB assembly into the case.

As shown in the photo, tilt the assembly and insert the TRRS socket end first to position it correctly.

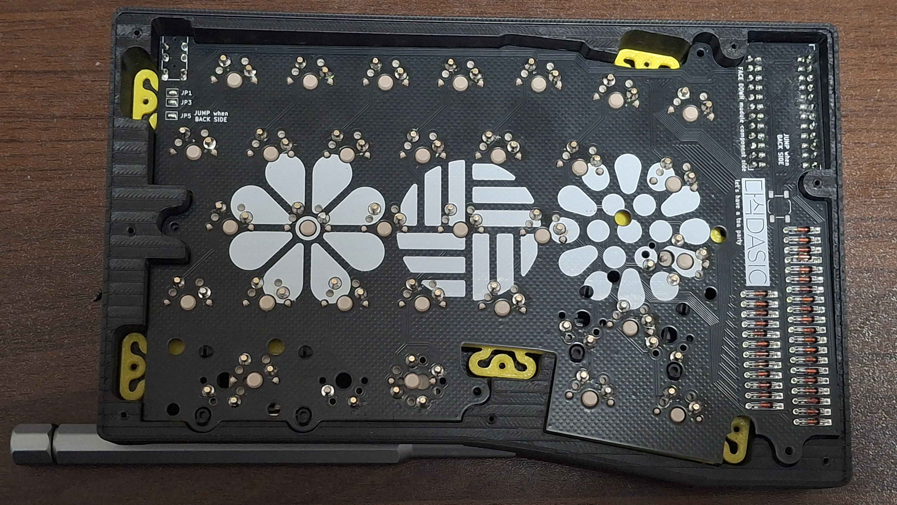
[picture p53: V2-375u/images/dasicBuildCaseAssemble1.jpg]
case1


**NOTICE: The photo avove is for V1, you must position dev board and jack on back side (opposite side).**

Once the assembly is inserted into the case, it will look like this.

- Securing only the plate with screws gives a softer typing feel. There are 5 screw points per keyboard half.

- Securing the PCB as well gives a firmer typing feel. There are 4 additional screw points per keyboard half.

After securing the screws, attach the back plate to the case. There are 7 fastening points per keyboard half.

Finally, attach the 4 bumpon pieces at the bumpon positions on the each back plate, and you are done.

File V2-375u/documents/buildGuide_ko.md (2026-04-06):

# 빌드 가이드

DASIC의 빌드 가이드입니다.

**이 빌드가이드의 사진은 V1 기준이며, V2를 위한 빌드가이드는 제작중입니다. 지문이 더 정확하니, 지문을 우선시하여 읽어주세요.**

### 추가 자료

[**준비물과 구매처 가이드**](preparation_ko.md)

[**납땜 팁**](solderingTip_ko.md)

### 제조 예상 가격

한 세트만 빌드할 때:

fabPCB

fabCase

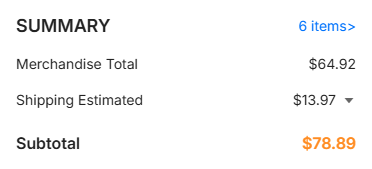
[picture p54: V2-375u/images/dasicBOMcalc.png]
fabResult


다섯 세트를 빌드할 때:

fab10PCB

fab5Case

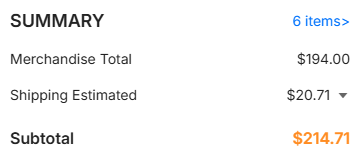
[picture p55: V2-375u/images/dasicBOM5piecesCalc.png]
fab5Result


빌드시 제일 개당 단가가 적은 건 다섯 세트(약 45달러)지만, 두 세트만 빌드해도 개당 제조 단가를 55달러 가량으로 가져갈 수 있습니다.

## 컨트롤러 보드에 펌웨어 올리기

rp2040 보드를 사용할 때를 상정했습니다.

컨트롤러 보드의 Boot 버튼을 누르며 usb를 연결하면 이동식 디스크가 하나 뜹니다. (이를 dfu모드라고 합니다.)

[uf2examples 폴더](../firmware/nologoRP2040qmk/examples) 안에 있는 .uf2 파일을 해당 이동식 디스크에 집어넣으면 펌웨어가 들어갑니다. vial 펌웨어를 올리시는 걸 추천드립니다.

펌웨어에는 [qmk](https://qmk.fm/)를 사용하고 있습니다. 펌웨어를 직접 만들고 싶다면 "firmware/qmk" 경로 내의 "modubu" 폴더를 "qmk_firmware\keyboards" 경로로 붙여넣어 qmk msys를 이용해 빌드하면 됩니다.

완전히 조립된 이후 펌웨어를 올리려면 버튼을 누를 수 없어 문제가 생깁니다. 그래서 **컨트롤러 보드를 납땜하기 전에 펌웨어를 올리시는 걸 추천합니다**.

펌웨어를 올린 이후 dfu 모드에 들어갈 땐 몸으로부터 가장 바깥쪽 최하단의 스위치(ctrl, fn 위치)를 누른 채 키보드를 연결하면 됩니다.

## 컨트롤러 보드 납땜하기

headerPin0

headerPin1

우선 컨트롤러 보드와 동봉되는 헤더핀의 한 줄을 뗍니다. usb와 제일 가까운 헤더 핀 부분은 납땜하지 않기 때문입니다.

processorSolder0

processorSolder1

**프로세서 부품이 아래로 향하게, usb와 제일 가까운 핀 부분은 비워둔 채로** 헤더 핀을 끼워 납땜합니다.

빵판이 있다면 위와 같이 빵판에 헤더 핀을 안착시키면 편하게 납땜할 수 있습니다.

processorSolder2

방금전에 납땜한 프로세서 보드를 pcb에 납땜합니다.

**프로세서 보드를 올린 면이 pcb의 뒷면이 되고, 반대편 면은 앞면이 됩니다. 왼손과 오른손에 맞춰 pcb를 뒤집어 프로세서 보드를 올려주세요.**

processorSolder4

pcb의 앞면을 보고 헤더 핀이 앞면 패드에 연결되도록 모두 땜합니다.

중간 구멍에 tht가 없으며, 위아래로 패드가 있는 구조입니다. 패드와 핀을 납을 충분히 많이 올려 연결해주시기 바랍니다.

## 커넥터 납땜하기 & 점프하기

componentPositioning

jackSolder0

jackSolder1

jackSolder2

각 손의 뒷면 부분에 커넥터가 오도록 TRRS 커넥터를 배치하고, 앞면에서 납땜합니다. 납땜할 때 마스킹 테이프 등으로 고정해두면 좋습니다.

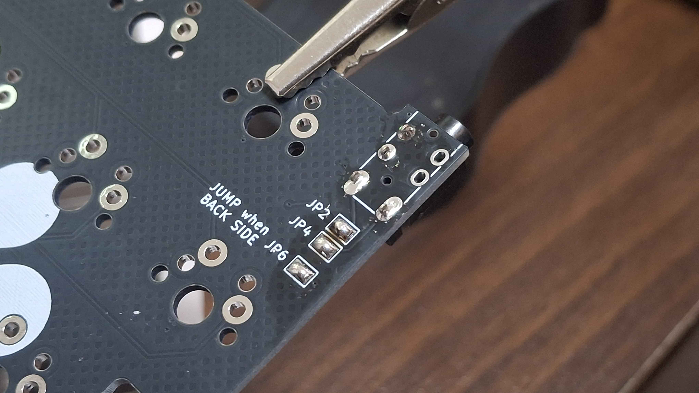
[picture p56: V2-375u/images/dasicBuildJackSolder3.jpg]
jackSolder3


뒷면을 보고 있는 상태에서, "JUMP when BACK SIDE"라는 문구 주변의 점퍼 세 점을 땜납으로 점프합니다. 반대쪽 면(=커넥터가 올라가 있지 않는 앞면)은 하지 않습니다.

점퍼를 땜할 땐 먼저 인두기 팁에 솔더페이스트를 잔뜩 묻히고 거기에 납을 방울지게 올린 뒤, 이 상태로 방울을 점퍼에 가져다 댄 다음 두 점퍼가 서로 이어졌다 싶을 때 뗍니다.

- 점퍼가 서로 이어졌지만 납이 날카롭고 뾰족하게 올라온다면 솔더 페이스트를 팁에 더 묻혀주세요.

- 점퍼가 서로 안 붙고 패드에 방울만 진다면, 납을 팁에 더 올려주세요.

- 점퍼가 서로 이어지면서 딱 유선형으로 방울지게 올라오게 되었을 때가 성공입니다. 다음 점퍼를 땜하면 됩니다.

잘 안되면 점퍼 부분을 잠시 식혔다가, 충분한 양의 플럭스를 팁과 점퍼에 묻히고 다시 시도해보세요.

## 다이오드 납땜하기

diodeTip

THT 다이오드를 사용한다면, 위의 사진과 같이 다이오드의 다리를 ㄷ자로 미리 굽혀서 준비합니다.

우선 갯수가 더 많은 열 쪽의 다이오드를 먼저 땜합니다. 앞면인지 뒷면인지는 상관없으며, **모든 다이오드 방향이 바깥쪽을 향해야 합니다.**

DiodeSolder0

DiodeSolder1

DiodeSolder2

DiodeSolder3

납땜을 마치면 다이오드의 뻗어난 잔가지 다리부분을 니퍼로 모두 자릅니다. 주변 패드에 닿지 않게 바짝 당겨서 잘라둡니다. 자를 땐 튕겨나가지 않도록 꼭 다리를 손가락으로 잡고 자릅시다.

DiodeSolder4

DiodeSolder5

DiodeSolder6

처음 열을 마치면 다음 열도 똑같은 순서대로 땜합니다. **다이오드의 다리 부분이 서로 부딪히지 않도록 조심해 주세요.**

SMD 다이오드를 사용할 땐 다이오드 위치의 한 쪽 패드에 납을 묻히고, 납을 묻힌 패드에 열을 다시 가합니다.

패드의 납이 녹았을 때 SMD 다이오드의 한 쪽 다리를 가져다 위치를 정렬해 붙힌 뒤, 반대쪽 다리를 땜합니다.

## (선택) SMD 스위치 납땜하기

smd 스위치는 reset 핀과 연결되어있습니다. rp2040이 아닌 프로세서 보드는 이 스위치로 dfu 모드에 들어가게 됩니다. 이 스위치는 뒷면에 붙여주세요.

붙이는 방식은 SMD 다이오드와 동일합니다. 스위치 위치의 한 쪽 패드에 납을 묻히고, 납을 묻힌 패드에 열을 다시 가합니다.

패드의 납이 녹았을 때 스위치의 한 쪽 다리를 가져다 위치를 정렬해 붙힌 뒤, 나머지 다리를 땜합니다.

## (선택) 밀맥스 납땜하기

millmax0

millmax1

위의 사진과 같이, 밀맥스를 앞면에서 집어넣고 마스킹 테이프 등으로 고정한 뒤 납땜합니다.

밀맥스를 집어넣는 위치는 앞면 기준 패드가 보이지 않는 구멍, 뒷면 기준 패드가 보이는 쪽의 정 중앙입니다.

millmax2

Caps & Enter 부분의 밀맥스는 사진을 참고하며 주의해 고정합니다.

앞면 기준에서는 중앙이 아닌 쪽으로 정렬해야 하며, 뒷면으로 볼 땐 패드 모양의 중앙에 정렬되어있어야 합니다.

## 스태빌라이저 조립하기

stabilizers

2u 이상의 키캡이 설치되는 부분에 전부 스태빌라이저를 채결해줍니다.

기본적으로 왼쪽 shift, 스페이스바 부분 두 곳, 엔터 총 4곳에 채결하게 됩니다.

## 조립상태 확인하기

납땜 위치와 상태를 확인하며 조립이 제대로 됐는지 확인합니다. 다이오드가 올라가 있는 면은 방향만 맞다면 상관 없습니다.

## 스위치와 보강판 조립하기

plates1

plates2

키보드 보강판에 미리 스위치와 블로커를 체결합니다. 사진엔 키캡도 체결되어있으나, 키캡까지 체결할 필요는 없습니다.

plates0

블로커를 채결할 땐 위의 사진처럼 나사를 조여 채결합니다. halfScrew 버전을 쓴다면 튀어나온 한 쪽은 보강판에 걸친 뒤 나머지 한 쪽을 나사로 고정합니다.

plates3

**주의사항: 이 사진은 V1 기판입니다. V2에선 개발보드와 trrs 잭을 뒷면(사진의 반대편)에 올려두어야 합니다**

이 위에 사진처럼 조립한 보드를 얹고, 스위치를 납땜합니다.

## 케이스 조립하기

case0

**주의사항: 이 사진은 V1 기판입니다. V2에선 개발보드와 trrs 잭을 뒷면(사진의 반대편)에 올려두어야 합니다**

보강판과 pcb의 조립체를 케이스에 집어넣습니다.

사진과 같이 TRRS 소켓부터 먼저 위치를 잡을 수 있도록 기울여 집어넣습니다.

case1

**주의사항: 이 사진은 V1 기판입니다. V2에선 개발보드와 trrs 잭을 뒷면(사진의 반대편)에 올려두어야 합니다**

케이스에 조립체를 집어넣으면 다음과 같은 모양이 됩니다.

- 보강판만 나사를 채결하면 부드러운 타건감을 얻을 수 있습니다. 고정하는 곳은 키보드 한 쪽당 총 5곳입니다.

- pcb까지 나사를 채결하면 좀 더 단단한 타건감을 얻을 수 있습니다. 추가로 고정할 곳은 키보드 한 쪽당 총 4곳입니다.

나사를 채결하면 백플레이트를 덮어 케이스와 채결합니다. 고정하는 곳은 키보드 한 쪽당 7곳입니다.

마지막으로 각 백플레이트의 범폰 위치에 범폰 4조각을 붙이면 완성입니다.

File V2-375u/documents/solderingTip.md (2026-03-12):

# Soldering Tips

A collection of soldering advice and tips.

This documents is translated by generative AI, so there can be some misleading texts.

## Supplies

- Soldering iron & stand: A chisel tip is the most convenient to work with. I recommend getting one that can maintain a temperature of at least 400–500°C.

- Solder: Choose between leaded and lead-free solder. Leaded solder is less stressful to work with, but it is not good for your health.

- Solder paste (flux): **The god of soldering.** If your solder joints are not turning out well, frequently wipe and coat the iron tip with paste flux.

- Damp sponge/paper towel, or a tip cleaner (brass wool): Used to wipe residual solder off the iron tip.

- Solder wick or solder sucker: Used to fix bad solder joints. For beginners, solder wick is recommended.

- Flush cutters: Used to clip the legs of THT diodes after soldering.

## Ventilate Your Workspace

The metal fumes from melting solder are a concern, but they are actually quite minimal. The bigger issue is the smoke from the rosin flux inside the solder burning and melting — it is quite harmful and produces a lot of smoke. It is very bad for your health, so ventilate the area, or if ventilation is not possible, make sure to use an air purifier. Always wear a mask.

## Double-Check Before Soldering Components

It is easier to prevent a bad solder joint than to fix one. To correct a solder joint, apply flux to solder wick and press it against the joint with the iron, or apply a small amount of flux to the iron tip, melt the solder, and simultaneously press a solder sucker against it to absorb the solder.

## Apply Flux If Solder Is Not Sticking

Melt flux onto the iron tip to coat it, or use a flux pen to apply it directly to the PCB pads.

## Touch the Iron First When Starting, Remove It Last When Finishing

Place the iron on the pad first to preheat the PCB and component, then melt the solder onto the joint. When finishing, remove the solder first, then remove the iron last.

## Use Masking Tape to Temporarily Hold Components

For components like sockets, securing them with masking tape before soldering is helpful. This is especially important when you need to flip the board over, as components can be difficult to hold in place.

## Clean the Flux After Soldering

Scrub the remaining flux and any areas prone to short circuits thoroughly using a toothbrush dipped in isopropyl alcohol. You can also spray alcohol on the board, scrub with a toothbrush, and let it dry. Keyboard key inputs may work fine with residual flux, but encoders and analog inputs are more susceptible to issues caused by flux bridging.

## If Something Goes Wrong, Reflow and Clean

Problems can arise from cold joints, insufficient solder, excess solder bridging neighboring pads, or electrical interference from flux residue. In most cases, reflowing the solder joint and cleaning the flux will resolve the issue.

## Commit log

2026-03-04 upload backplate and keyboard plate for fr4 fab
    [dasicBackplate-B_Cu.gbr, dasicBackplate-B_Mask.gbr, dasicBackplate-B_Paste.gbr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]
2026-03-04 add gerber zip
    [dasicPlate-B_Cu.gbr, dasicPlate-B_Mask.gbr, dasicPlate-B_Paste.gbr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]
2026-03-04 move plates gerber file to case folder
    [dasicBackplate-B_Cu.gbr, dasicBackplate-B_Mask.gbr, dasicBackplate-B_Paste.gbr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]
2026-03-04 upload right side case and blocker step
    [dasicBackplateLightR.stl, dasicBlockerHalfScrew.stp, dasicBlockerScrew.stp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]
2026-03-04 rename to proper one
    [dasicPlate.kicad_pcb]
2026-03-09 add hotswap version
    [dasicHotswap-B_Cu.gbr, dasicHotswap-B_Mask.gbr, dasicHotswap-B_Paste.gbr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]
2026-03-09 fix hotswap hole to proper layout
    [dasicHotswap-B_Cu.gbr, dasicHotswap-B_Mask.gbr, dasicHotswap-B_Paste.gbr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]
2026-03-11 add tilted case variation
    [dasic.3mf, dasicCaseTilt4degL.stp, dasicCaseTilt4degR.stp]
2026-03-12 upload korean readme and buildguides
    [dasicBackplate-B_Cu.gbr, dasicBackplate-B_Mask.gbr, dasicBackplate-B_Paste.gbr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]
2026-03-12 upload backplateLight vectorgraphic
    [dasicBackplateLight.dxf]
2026-03-12 upload estimated bom
2026-03-12 update bom images to proper one
2026-03-12 reupload pcb bom images to leadfree one
2026-03-15 add backside component case variation
    [dasicCaseBacksideComponentL.stp, dasicCaseBacksideComponentR.stp]
2026-03-19 update footprint of rp2040
2026-03-23 make default case setting to backsideComponent, and replaced module connector to advanced one. named as V2.
    [dasic-B_Cu.gbr, dasic-B_Mask.gbr, dasic-B_Paste.gbr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]
2026-03-26 make case variable for leaf spring mount
    [dasic.3mf, dasicCaseV2L.stp, dasicCaseV2R.stp]
2026-03-26 raise 0.5mm of bottom - to make acceptable space for backplate
    [dasic.3mf, dasicCaseV2L.stp, dasicCaseV2R.stp]
2026-03-27 0.5mm processor hole adjustment
    [dasic.3mf, dasicCaseV2L.stp, dasicCaseV2R.stp]
2026-03-29 Change folder structure to version based
    [dasic-B_Cu.gbr, dasic-B_Mask.gbr, dasic-B_Paste.gbr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]
2026-03-31 add 3.75u variants for some generous cutstom keycaps
    [dasic-B_Cu.gbr, dasic-B_Mask.gbr, dasic-B_Paste.gbr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]
2026-03-31 update hotswap plate for reversible caps/enter
    [dasicHotswap-B_Cu.gbr, dasicHotswap-B_Mask.gbr, dasicHotswap-B_Paste.gbr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]
2026-03-31 hotfix for 375u keyboard plate
    [dasicPlate-B_Cu.gbr, dasicPlate-B_Mask.gbr, dasicPlate-B_Paste.gbr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]
2026-03-31 update 375u case holes to proper one
    [dasic375.3mf, dasic375CaseL.stp, dasic375CaseR.stp]
